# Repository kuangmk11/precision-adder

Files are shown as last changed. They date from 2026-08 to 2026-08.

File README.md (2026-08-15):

# Precision Adder v2.2
This is a precision CV source and adder. It has four stages, each with an input, an output and a passthru. Each stage's **output** normals down to the next stage's input, so with a single cable into `IN1` the stages cascade and their offsets sum; patching into any `IN` breaks the normal above it. The passthru is a buffered copy of that stage's input, so with nothing patched `PT2` = `OUT1`, `PT3` = `OUT2`, and so on.

Each section provides a different voltage to be added to the input: +/- 2v, +/- 1v, +/- .5833333v (a fifth), +/- .4166666v (a fourth)

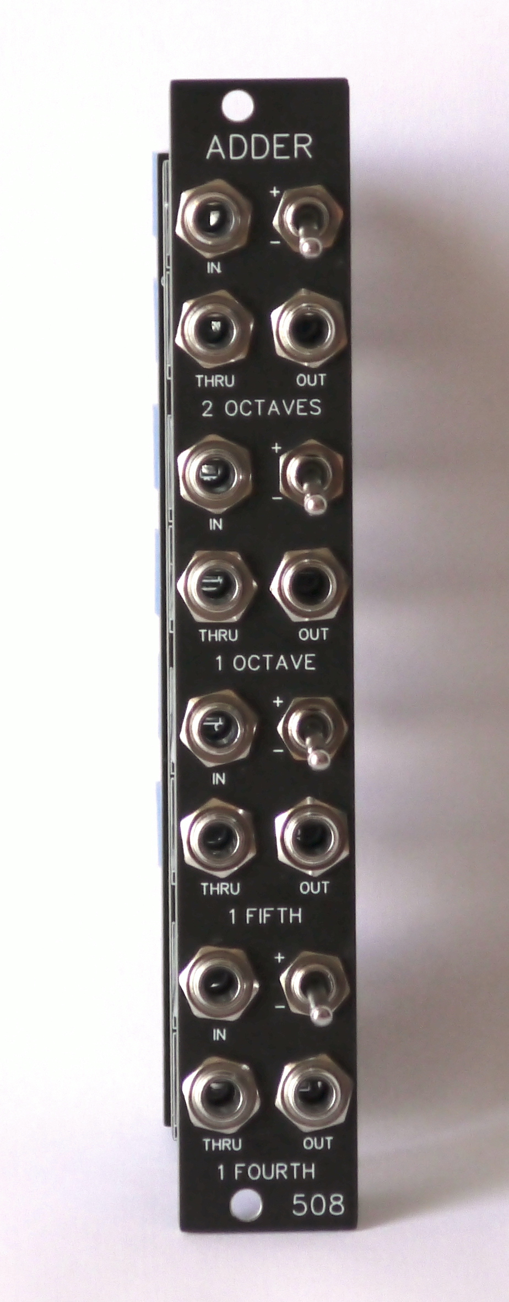
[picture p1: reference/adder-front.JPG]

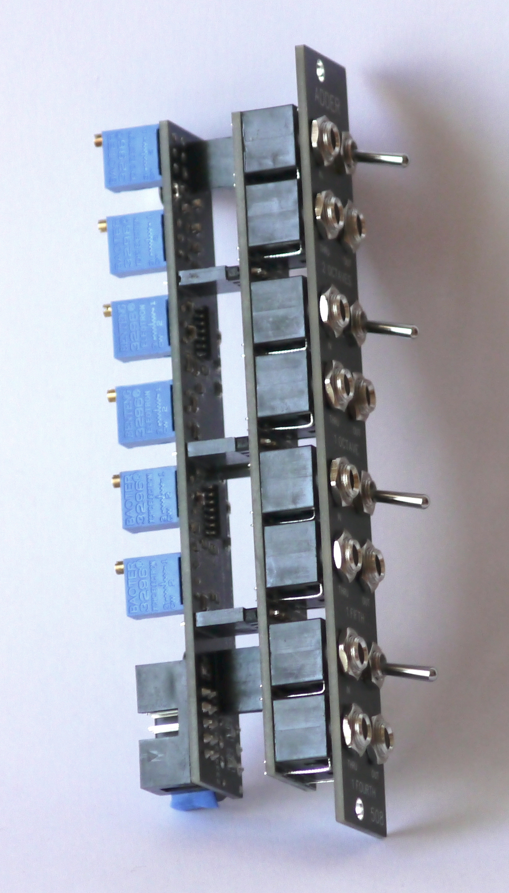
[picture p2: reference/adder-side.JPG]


## The v2.2 reference build

Everything shipped for the built v2.2 board now lives in [`reference/`](reference/): its
schematic PDF, the three gerber archives, the EasyEDA bill of materials and the photos
above. That revision is finished and is not being changed — the directory is there so the
built design stays available for anyone assembling a v2.2, and as the thing v3 is measured
against.

Two v2.2 documents deliberately stay outside it. [`docs/v2.2-topology.md`](docs/v2.2-topology.md)
is the ladder maths read off the v2.2 schematic, and it is a live input to v3 rather than an
artifact of the old build — `tools/gen_schematic.py` works from it, and `docs/v3-BOM.md`
verifies against it. [`docs/DESIGN-LOG.md`](docs/DESIGN-LOG.md) spans both revisions.

## Available intervals

The switches are SPDT ON-ON, so a stage in the chain always contributes either its positive or its negative offset — there's no center-off. Using the switches alone gives 4 stages x 2 states = **16 combinations** and 13 distinct voltages.

A stage can also be bypassed by patching its `PT` (passthru) into the `IN` of the next stage, feeding that stage's input forward instead of its output. That makes each stage a 3-state element (**+**, **-**, or **bypassed**), for **81 configurations** and **39 distinct voltages**.

The full set is symmetric, so the table below lists magnitudes only — for the negative of any row, flip every `+`/`-` (bypasses stay bypassed). `o` = stage bypassed.

| Semitones | Volts | Interval | Settings (2oct · 1oct · 5th · 4th) |
|---:|---:|---|---|
| 48 | 4.0000 | 4 oct | `+ + + +` |
| 43 | 3.5833 | 3 oct + 5th | `+ + + o` |
| 41 | 3.4167 | 3 oct + 4th | `+ + o +` |
| 38 | 3.1667 | 3 oct + M2 | `+ + + -` |
| 36 | 3.0000 | 3 oct | `+ + o o` · `+ o + +` |
| 34 | 2.8333 | 2 oct + m7 | `+ + - +` |
| 31 | 2.5833 | 2 oct + 5th | `+ + o -` · `+ o + o` |
| 29 | 2.4167 | 2 oct + 4th | `+ + - o` · `+ o o +` |
| 26 | 2.1667 | 2 oct + M2 | `+ o + -` |
| 24 | 2.0000 | 2 oct | `+ + - -` · `+ o o o` · `+ - + +` · `o + + +` |
| 22 | 1.8333 | 1 oct + m7 | `+ o - +` |
| 19 | 1.5833 | 1 oct + 5th | `+ o o -` · `+ - + o` · `o + + o` |
| 17 | 1.4167 | 1 oct + 4th | `+ o - o` · `+ - o +` · `o + o +` |
| 14 | 1.1667 | 1 oct + M2 | `+ - + -` · `o + + -` |
| 12 | 1.0000 | 1 oct | `+ o - -` · `+ - o o` · `o + o o` · `o o + +` |
| 10 | 0.8333 | m7 | `+ - - +` · `o + - +` |
| 7 | 0.5833 | 5th | `+ - o -` · `o + o -` · `o o + o` |
| 5 | 0.4167 | 4th | `+ - - o` · `o + - o` · `o o o +` |
| 2 | 0.1667 | M2 | `o o + -` |
| 0 | 0.0000 | unison | `o o o o` · `+ - - -` · `o + - -` · `o - + +` · `- + + +` |

### The pattern

Every reachable offset is **0, ±2, or ±5 semitones (mod 12)** — unison, M2, 4th, 5th, m7, and their octaves. Within ±48 semitones every such value is reachable *except* ±46. Thirds, tritones, sixths, and single semitones are not available, because a fifth and a fourth can only ever combine to an octave (7+5) or a whole step (7-5).

The usable pitch-class set is therefore the suspended pentatonic `{0, 2, 5, 7, 10}`, spread across a full ±4 octaves in 1/12 V steps.

### Patching notes

- **Leading bypasses are free** — plug your CV into `IN2` / `IN3` / `IN4` instead of `IN1`.
- **Trailing bypasses are free** — take your output from the last active stage's `OUT` instead of `OUT4`.
- **Only interior bypasses cost a cable**: one patch, `PTn` -> `IN(n+1)`, per skipped stage.
- Where a row lists multiple settings, prefer the one with bypasses at the edges — same voltage, fewer cables. For example 2 oct + 4th is `+ + - o` with no cables, versus `+ o o +` with two.

## v3 proposal (unbuilt)

v2.2 is a serial interval adder with a redundant interval set. v3 keeps the cascade, fixes the set, and reorganises the panel around what the cascade is actually good at — stacking intervals into chords.

The interval problem first: because a fifth plus a fourth is exactly an octave (7 + 5 = 12), two of v2.2's four stages collapse into a redundant third. 81 configurations produce only 39 distinct voltages, and the output can never leave the pitch classes `{0, 2, 5, 7, 10}` — no thirds, no sixths, no tritone, no single semitones.

### Four changes

**1. ON-OFF-ON switches.** v2.2 uses SPDT ON-ON, which is why bypassing a stage costs a patch cable. A subminiature ON-OFF-ON is the same footprint at essentially the same price, and the center detent gives each stage a native off position. Every configuration becomes reachable from the front panel with no patching. (Doepfer's A-185-2 has always done it this way — see the comparison below.)

**2. Drop `IN2`-`IN4` and `PT2`-`PT4`.** Outputs normal down to the next input, so with nothing patched `PT2` = `OUT1`, `PT3` = `OUT2`, `PT4` = `OUT3`. Those passthrus are duplicates of the output above them. The extra inputs existed to break the cascade, which the center-off switch now does better. Six jacks were doing the work of two.

**3. Sum three inputs at the front.** `IN1` + `IN2` + `IN3` at unity gain feed the head of the cascade. This is the multi-source summing the module is named for — keyboard plus sequencer plus offset — and it is what the freed panel space buys. `PT` becomes the buffered *sum* of the inputs: an untransposed root that stays put while the cascade transposes everything above it.

**4. Collapse the two octave stages into one, and make stages 2-4 thirds.** Stage 1 becomes a 5-state octave control (±1, ±2, off) from two toggles, freeing a stage. Stages 2 and 3 get a three-position quality switch selecting **4th / maj 3rd / min 3rd**, and stage 4 selects **5th / maj 3rd / min 3rd** — because stacked thirds are how chords are built, and the fifth on the last stage keeps the module's most-used interval one flip away.

### Panel

| | v2.2 | v3 |
|---|---:|---:|
| Jacks | 12 | 8 — `IN1` `IN2` `IN3` `PT` `OUT1`-`OUT4` |
| Switches | 4 | 8 — 2 per stage |
| **Positions** | **16** | **16** |

Same density as the board already built. No rotary, no new mechanical problem.



**This is a new panel, not v2.2's reused.** Earlier v3 drafts kept every v2.2 hole
position and only reassigned diameters, which forced the four outputs into two shared
rows. Grouping each stage instead — its two switches and its own output, boxed together —
needs six evenly spaced rows below the inputs, so the positions are refitted. The v3 main
board is new anyway.

Panel and drawing are generated by [`tools/gen_panel.py`](tools/gen_panel.py) from one
layout table, so they cannot disagree:

```sh
python3 tools/gen_panel.py            # writes the .kicad_pcb and the .svg, with a clearance report
python3 tools/gen_panel.py --table    # the hole schedule below
```

- [`docs/v3-panel.kicad_pcb`](docs/v3-panel.kicad_pcb) — board outline, holes and mounting
  slots on `Edge.Cuts`, silkscreen on `F.SilkS`. Holes are `Edge.Cuts` circles, so the fab
  routes rather than drills them; swap to NPTH pads if your fab prefers.
- [`docs/v3-panel.svg`](docs/v3-panel.svg) — the same geometry at 1:1 (1 unit = 1 mm,
  20 × 128.5 mm), for printing and review. The grey rings are hardware footprints — 8 mm
  Thonkiconn nut, 7.5 mm toggle nut — shown for clearance checking, not artwork, and not
  in the KiCad output.

Conventions — lettering, marks, label placement, mounting — are in
[`PANEL_STYLE_v1.02.md`](PANEL_STYLE_v1.02.md).

#### How it reads

Four jacks at the top: three summed inputs and `SUM`, the buffered sum that `PT` becomes.
`SUM` is an output, so it carries the ring — the panel's only closed circle, which is what
lets direction read at a glance. The ring has to clear the 8 mm nut to be visible at all,
and a 20 mm panel carrying two 8 mm nuts has 4 mm of slack in total, so at r 4.4 it ends up
0.28 mm from the cut on the outboard side. Still on the board, but well inside the 0.6 mm
edge margin, and a fab may trim the outer edge of it. Taken deliberately: a broken ring
reads worse than a clipped one. Below them, **four boxed groups, one per stage — polarity
switch, selector switch, that stage's output.** Each stage now owns its output, which the
old shared-row layout could not manage.

**Arrows trace the cascade** across the top pair, down into the bottom-left group, and
across the bottom pair — the order the stages actually sum in. The middle leg cannot be a
straight diagonal: about 4 mm of clear band between the box rows against a 10.8 mm column
pitch would need a 15° line, and the house routing is 0°, 90° and 45° only. So it drops,
takes a 45° knee, runs the band and turns down into the group it feeds. Where an arrow
crosses a box outline the outline is broken, the same way a group name breaks it.

`OUT1`–`OUT4` do not repeat the ring. Each already sits inside a named box that says which
stage it belongs to, and the style guide's rule against a second closed circle is what
keeps `SUM`'s ring meaningful. If you would rather every output ring, it is one line in the
generator.

Within a group: `+` above the polarity toggle, `−` below it, and **`0` beside its centre
detent**. The selector's two throws are labelled above and below it the same way.

That `0` matters more than it looks. A selector displays a value at all times, so without
it the panel reads as though a stage adds its interval even when the stage is switched off
— and the polarity toggle's centre, not the selector's, is what turns a stage off. One rule
covers both toggles now: **a three-position toggle's centre value is marked in the strip
between its nut and the box edge.** `OCT`'s magnitude switch is two-position and has no
centre, so it carries no such mark.

It is also why a plain fifth is one flip. At rest every polarity toggle is centred and the
module passes through untouched, whatever the selectors show; move stage 4's polarity to
`+` and its selector is already sitting on the `5`.

**The selector's centre detent carries the stage's odd interval** — the 4th on the two
`3RD` stages, the 5th on `5TH` — and the two throws are the two thirds, `MAJ` and `MIN`.
That is partly ergonomic, since the thirds are the pair you reach for when building a
chord, and partly forced: the centre mark is the only one with nowhere to go but the
1.2 mm strip between the toggle nut and the box, where a single character fits and two do
not. It is set at 1.0 mm, below the house 1.6 mm minimum, and is the one deliberate
exception on the panel.

#### Hole schedule

Origin top-left, millimetres, Y down — the drawing's own frame, not the old gerbers'.

| Y (mm) | X (mm) | Ø | What |
|---:|---:|---:|---|
| 16.60 | 4.80 | 6.0 | IN1 |
| 16.60 | 15.20 | 6.0 | IN2 |
| 28.60 | 4.80 | 6.0 | IN3 |
| 28.60 | 15.20 | 6.0 | SUM (output, ringed) |
| 44.80 | 4.80 | 5.0 | OCT polarity  +/o/− |
| 44.80 | 15.20 | 5.0 | 3RD polarity  +/o/− |
| 57.80 | 4.80 | 5.0 | OCT select  1/2 |
| 57.80 | 15.20 | 5.0 | 3RD select  MAJ/MIN (detent 4) |
| 68.80 | 4.80 | 6.0 | OUT1 |
| 68.80 | 15.20 | 6.0 | OUT2 |
| 88.00 | 4.80 | 5.0 | 3RD polarity  +/o/− |
| 88.00 | 15.20 | 5.0 | 5TH polarity  +/o/− |
| 101.00 | 4.80 | 5.0 | 3RD select  MAJ/MIN (detent 4) |
| 101.00 | 15.20 | 5.0 | 5TH select  MAJ/MIN (detent 5) |
| 112.00 | 4.80 | 6.0 | OUT3 |
| 112.00 | 15.20 | 6.0 | OUT4 |
| 3.00 | 12.50 | 6.4×3.2 | mounting slot, obround |
| 125.50 | 7.50 | 6.4×3.2 | mounting slot, obround |

Mounting follows the style guide's ≤ 6 HP rule: one 6.4 × 3.2 mm horizontal slot top-right
and one bottom-left, so the module can slide ±1.6 mm to meet its neighbours and cannot
pivot on a single screw per rail. v2.2's round Ø3.2 holes do not carry over.

#### What the generator checks, and what it cannot

`gen_panel.py` refuses to write if anything overlaps, and reports the tightest clearance in
each category. Currently: **0.15 mm** text-to-nut, **0.64 mm** text-to-text, **0.15 mm**
text-to-silk, **0.42 mm** text-to-ring, **0.60 mm** silk-to-edge, **1.40 mm** of material
at the worst hole, and **2.40 mm** between the closest two nuts. `SUM`'s ring is exempted
from the edge margin and reported separately, so the exception stays visible instead of
being absorbed into a looser rule.

Those come from a stroke-glyph model that assumes ink fills 0.62 em of each character
cell — conservative for the KiCad stroke font, but still a model. **KiCad's own DRC passes
with 0 violations and 0 unconnected items** (`tools/kicad-check.sh`), and the board plots
correctly from KiCad, mounting slots and all.

The two toggles in a group are 13.0 mm apart, leaving 5.5 mm between their nuts — up from
4.9 mm in the row-based draft, but still unproven on this hardware, since v2.2 stacks no
toggles at all. Print the SVG at 100%, check it measures 20 × 128.5 mm, and try the pairs
with real fingers.

### Schematic

[`docs/v3-adder.kicad_sch`](docs/v3-adder.kicad_sch), generated by
[`tools/gen_schematic.py`](tools/gen_schematic.py) from a netlist table:

```sh
python3 tools/gen_schematic.py             # writes the .kicad_sch, with a design report
python3 tools/gen_schematic.py --bom       # bill of materials
python3 tools/gen_schematic.py --netlist   # every net and what is on it
```

**It is a scaffold, not a finished drawing.** Connectivity is complete and correct;
placement is a plain grid, and every connection is made with a net label on a short pin stub
rather than by routing wires. That is deliberate — label-based connectivity cannot be got
subtly wrong the way routed wires can, and rearranging symbols in KiCad afterwards breaks
nothing. Expect to spend time on layout, not on wiring.

Topology follows [`docs/v2.2-topology.md`](docs/v2.2-topology.md). The reference block, the
power block and the summing topology are v2.2's, unchanged. 102 parts, 72 nets, 12 op-amp
channels across three OPA4196 — 11 used, one spare tied off as a follower.

**Only the lower ladder segments need to be precise.** A tap's voltage is set by the ratio
of the segments below it to the whole chain, and the trimmer sits in series at the top, so
the top segment's absolute value is absorbed by trimming — which is why the BOM shows
5.5k, 24.5k and 22.5k and why that does not matter. Use the nearest E96 part and let the
trimmer take up the difference. What does matter is the ratio between the small segments
(1k, 3k, 12k), and that is where hand-matched parts earn their keep.

Alongside the schematic the generator writes `adder.kicad_sym`, `v3-adder.kicad_pro` and a
`sym-lib-table`, so the project opens with its symbol library resolved rather than warning
once per symbol.

**KiCad's own ERC passes with 0 errors.** Run it yourself:

```sh
KICAD_CLI="/path/to/kicad-cli" tools/kicad-check.sh    # ERC, DRC and plots into .kicadcheck/
```

The 23 remaining ERC warnings are all `footprint_link_issues` on the custom parts — jacks,
toggles, trimmers, ferrites, the Eurorack header. Those footprints are yours to supply, and
a name that does not resolve is a more honest placeholder than a wrong one that does. Stock
KiCad footprints are used everywhere they exist, so the passives, op-amps, regulators and
diodes resolve on any install.

### Bill of materials

[`docs/v3-BOM.md`](docs/v3-BOM.md) is the parts list, with the tolerance reasoning for every
line. [`docs/BOM_v3_DigiKey.csv`](docs/BOM_v3_DigiKey.csv) alongside it is an upload-ready
DigiKey list covering 93 of the parts; its sourcing notes are the last section of `v3-BOM.md`.

Three things are worth knowing before ordering. The **E24 values this design depends on are
stocked in 0.1 %** — Panasonic's ERA-8 series has both the 3.00k and the 12.0k, so choosing E24
over E96 for the exact 3:1 ratio costs nothing in availability. The **ON-ON-ON DPDT has no
DigiKey equivalent** in this form factor and must come from a synth DIY shop, along with the
jacks and the axial ferrites. And **C9/C10 need a decision**: the MnO2 tantalum that satisfies
the ESR requirement is a surface-mount part, which does not fit the through-hole footprint the
BOM currently specifies for them.

#### Switches

Taiway series 200 subminiature throughout — `T1` actuator, `B1` bushing, `M2` PC thru-hole,
`Q` silver, `E` epoxy:

| Function | Part | Used for |
|---|---|---|
| SPDT ON-OFF-ON | `200-MSP3-T1B1M2QE` | polarity, ×4 |
| SPDT ON-ON | `200-MSP1-T1B1M2QE` | `OCT` magnitude, ×1 |
| DPDT ON-ON-ON | `200-MDP6-T1B1M2QE` | quality selectors, ×3 |

The `B1` bushing is **10-48 UNS, Ø4.80** and Taiway's recommended panel hole is **Ø4.95** —
the panel's Ø5.0 is right. There is also an optional 4.55 mm flat in the hole for
anti-rotation, which the panel does not cut, so the switches are held by nut torque alone.

**A DPDT ON-ON-ON is a 1-of-3 selector only if you cascade its poles.** Pins 1‑2‑3 are pole
A with 2 common, 4‑5‑6 are pole B with 5 common. Pole A's common is the output; one of its
throws is a tap outright, the other feeds pole B's common, and pole B picks between the
remaining two. Tying the commons together instead would short two ladder taps in every
position.

`MDP-6`'s contact sequence, from Taiway:

| Position | Contacts |
|---|---|
| 1 | `2-3, 5-6` |
| 2 (centre) | `2-3, 5-4` |
| 3 | `2-1, 5-4` |

`ONONON_VARIANT = 1` in `tools/gen_schematic.py` encodes exactly this. `check_selector()`
walks each selector through all three positions from that table and asserts the output
reaches the intended tap and **exactly one** tap — the property that makes the cascade
trustworthy, since getting it wrong shorts two points of a resistor ladder rather than
failing loudly. Setting the variant to 2 makes it fail at the centre detent, as it should.

PC-mount terminals are on a **5.08 × 2.54 mm** grid, six pins, numbered 6‑5‑4 down one
column and 3‑2‑1 down the other.

**Orientation does not matter.** The body is symmetric, so fitting it 180° round swaps
diagonally opposite pads (6↔1, 5↔2, 4↔3) *and* reverses the lever — and those two cancel
exactly. Read against the board's own pad numbers from lever-up to lever-down, the sequence
is unchanged. The pin numbers on a reversed part are wrong; its behaviour is not.
`check_rotation_symmetry()` asserts this against the contact table, so it stays true if the
table is ever edited.

The generator additionally checks, before writing: every `lib_id` resolves as a full
`library:name` string and every instantiated unit has a matching body; every pin coordinate
read back out of the written file lands on a wire endpoint, so the label stubs really do
attach; no pin is unconnected; no net has fewer than two connections; no reference is used
twice and no pin appears on two nets; and every ladder tap computes to its interval voltage
exactly with the trimmer centred.

### Stages

Read the selector column as **up / _centre detent_ / down**, which is how the panel is
marked: the two throws are the thirds, the detent is the stage's odd interval.

| Stage | Panel group | Control | Selects — up / _detent_ / down | Values | Volts |
|---|---|---|---|---|---|
| 1 | `OCT` | on-off-on + `1/2` on-on | 1 oct / — / 2 oct | ±12, ±24 st | 1.000000 / 2.000000 |
| 2 | `3RD` | on-off-on + quality on-on-on | M3 / _4th_ / m3 | ±4, ±5, ±3 st | 0.333333 / 0.416667 / 0.250000 |
| 3 | `3RD` | on-off-on + quality on-on-on | M3 / _4th_ / m3 | ±4, ±5, ±3 st | 0.333333 / 0.416667 / 0.250000 |
| 4 | `5TH` | on-off-on + quality on-on-on | M3 / _**5th**_ / m3 | ±4, ±7, ±3 st | 0.333333 / 0.583333 / 0.250000 |

The values are unchanged from earlier drafts — only which throw carries which. Stage 1's
magnitude switch is a two-position ON-ON, so it has no detent.

Stage 4 takes a **5th** where stages 2 and 3 take a 4th. That buys back the one-switch fifth — the module's most-used interval — and on the chord side it turns stage 4 into an extension selector, since stages 2 and 3 have already built the triad by the time the signal reaches it.

**1715 configurations, 83 distinct voltages, fully chromatic across ±41 semitones (±3.42 octaves), all 12 pitch classes.**

### Chords

The cascade means each output is a running sum, so `OUT1`-`OUT4` are stacked intervals, with `PT` available as an untransposed root beneath them. **Stages 2 and 3 set the triad; stage 4 sets the extension.**

| Triad (st2 + st3) | st4 = m3 | st4 = M3 | st4 = 5th |
|---|---|---|---|
| M3 + m3 — **major** | dominant 7th | major 7th | add9 |
| m3 + M3 — **minor** | minor 7th | minor-major 7th | minor add9 |
| m3 + m3 — **diminished** | diminished 7th | half-diminished | dim add b9 |
| M3 + M3 — **augmented** | augmented maj7 | augmented (8ve) | augmented #9 |

Twelve voicings from three switches, and the triad is already correct on `OUT1`-`OUT3` before stage 4 is touched. The 4th position on stages 2 and 3 adds sus and quartal voicings on top of that.

The `OCT` stage transposes the whole chord while `PT` holds the original root — so a pedal tone stays put underneath a transposed voicing.

This is what the old `{octave, 5th, 4th, maj 3rd}` set could not do: fifths and fourths do not stack into chords.

### Transposition chart

Taking `OUT4` as a single transposed voice. `o` = switch centered. Within any octave the settings are identical, so the `OCT` stage handles everything above; negative intervals are the mirror image.

| Semitones | Volts | Interval | OCT | st2 | st3 | st4 | Flips |
|---:|---:|---|:---:|:---:|:---:|:---:|---:|
| 0 | 0.0000 | unison | `o` | `o` | `o` | `o` | 0 |
| 1 | 0.0833 | min 2nd | `o` | `o` | `+4th` | `-M3` | 2 |
| 2 | 0.1667 | maj 2nd | `o` | `o` | `+4th` | `-m3` | 2 |
| 3 | 0.2500 | min 3rd | `o` | `o` | `o` | `+m3` | 1 |
| 4 | 0.3333 | maj 3rd | `o` | `o` | `o` | `+M3` | 1 |
| 5 | 0.4167 | 4th | `o` | `o` | `+4th` | `o` | 1 |
| 6 | 0.5000 | tritone | `o` | `o` | `+m3` | `+m3` | 2 |
| 7 | 0.5833 | 5th | `o` | `o` | `o` | `+5th` | **1** |
| 8 | 0.6667 | min 6th | `o` | `o` | `+4th` | `+m3` | 2 |
| 9 | 0.7500 | maj 6th | `o` | `o` | `+4th` | `+M3` | 2 |
| 10 | 0.8333 | min 7th | `o` | `o` | `+m3` | `+5th` | 2 |
| 11 | 0.9167 | maj 7th | `o` | `o` | `+M3` | `+5th` | 2 |
| 12 | 1.0000 | octave | `+1` | `o` | `o` | `o` | 1 |

Every interval up to the octave is one or two switch positions, and the octave, 4th, 5th, maj 3rd and min 3rd are all single flips. The remaining rows read as stacks — a tritone is two minor thirds, a major 7th is a major third over a fifth.

### Build notes

- **BOM:** 4x `SUBMINI_SPDT ON-OFF-ON` (polarity, one per stage), 3x `ON-ON-ON` DPDT (quality, stages 2-4), 1x `ON-ON` (octave magnitude). 8 jacks instead of 12.
- Resistor values needed: 1.000000 and 2.000000 V (already on the v2.2 board), 0.583333 V (the existing 5th) and 0.416667 V (the existing 4th), plus 0.333333 V and 0.250000 V (new). Every v2.2 divider is reused; only the two third values are added.
- The three input summing resistors must be matched — this is where the "precision" in the name is spent. Doepfer specs 0.1% on the A-185-2 for the same reason.
- **Headroom:** three summed inputs plus up to ±3.25 octaves of offset can rail a ±12 V supply. Worth checking the worst case for the intended sources rather than assuming.
- No normalling on `IN2`/`IN3` — an unpatched input should contribute 0 V, not a fixed offset. (Doepfer normals its inputs to +1 V so they double as octave switches; here the octave stage already does that job.)
- All inputs stay at unity gain. An attenuator on one input would be useful for modulation depth, but it compromises the precision identity — that is the A-185-2's tradeoff, not this one's.

## Comparison: Doepfer A-185-2

The obvious commercial reference point, and the source of the ON-OFF-ON idea. (The A-185-2V is the Vintage Edition — beige panel, functionally identical.)

The A-185-2 is a **summer first and an offset generator second**. It has four CV inputs — one with a log attenuator, three without — each with a three-position add/off/subtract switch, and every input normalled to +1 V. Its intended job is combining keyboard + sequencer 1 + sequencer 2; the offset capability falls out of the normalling. Unpatched, you get three switches at ±1 octave plus the attenuated channel as a continuous 0...±1 V fine tune. Total range ±4 V, the same as v2.2, but the switched part is only `{0, ±12, ±24, ±36}` semitones — 7 distinct values out of 27 combinations, since all three sections are the same 1 V.

| | A-185-2 | v2.2 | v3 |
|---|---|---|---|
| Width | 6 HP | — | — |
| Summing inputs | 4 (1 attenuated) | 1 (+3 cascade breaks) | 3 |
| Interval stages | 4 | 4 | 4 |
| Switch type | ON-OFF-ON | ON-ON | ON-OFF-ON + ON-ON-ON |
| Bypass a stage | center detent | patch `PT`->`IN` | center detent |
| Offset values | 1 V x3 (octaves only) | 2, 1, 0.5833, 0.4167 V | 1/2 oct; 4th/M3/m3 x2; 5th/M3/m3 |
| Switched distinct values | 7 | 39 | 83 |
| Non-octave intervals | knob only, not exact | exact 4th/5th | exact 3rd/4th/5th |
| Fully chromatic | via knob, unrepeatable | no (5/12 pitch classes) | yes, ±41 st |
| Chord voices | 1 | 4 (cumulative) | 4 + root, 12 voicings |
| Inverting output | yes | no | no |
| Input attenuator | yes (log) | no | no |
| Outputs | 3x sum + 1x inverted | per-stage taps | per-stage taps + `PT` |
| A-100 bus CV | yes (JP5) | no | no |
| Accuracy | 0.1% matched | — | — |

**What the Doepfer cannot do:** produce an exact fifth. Its only non-octave path is a log potentiometer — you can get close by ear, but not to 0.583333 V repeatably, and not back to it after moving the knob. That gap is the reason this module exists.

**What this module cannot do:** invert or attenuate its input, or reach the A-100 bus. The ± switches negate each stage's own contribution, not the incoming CV; the A-185-2's inverting output negates the entire sum. That is a real feature absent here and not fakeable with the current topology.

They are complementary rather than competing — the Doepfer is the better general-purpose summer, this is the better interval and chord source. v3 narrows the gap on summing by taking three inputs at the front. The one thing worth taking wholesale is the switch: center-off is a BOM choice, not a design constraint, and v2.2 pays a patch cable per bypass for want of it.

Sources: [A-185-2 specification](https://doepfer.de/a185_2.htm), [Doepfer product page](https://www2.doepfer.eu/en/item/a185-2).

## Appendix: interval set study

Where the v3 numbers come from. All of it is reproducible with [`interval-study.py`](interval-study.py) (no dependencies, `python3 interval-study.py`).

### Method

Each stage contributes `+v`, `-v`, or `0`, so N stages give 3^N configurations. On v2.2 the zero state costs a patch cable (`PT` -> `IN` of the next stage) because the switches are ON-ON; on v3 it is the center detent of an ON-OFF-ON. The arithmetic is identical either way, so every chart below applies to both. Values are in semitones; 1 semitone = 1/12 V. Three metrics are reported:

- **distinct** — how many different output voltages the module can produce. Below the combination count means stages are redundant with each other.
- **chromatic ±N** — the widest symmetric range around 0 in which *every* semitone is reachable. This is the metric that matters; a set can have plenty of distinct values and still be useless for chromatic work.
- **pc** — how many of the 12 pitch classes are reachable at all.

Baseline for v2.2 `{24,12,7,5}`: **39 distinct / 81 combos, chromatic ±0, 5/12 pitch classes.**

### Chart 1 — one stage added to v2.2

| Added | Interval | Distinct | Chromatic | Pitch classes |
|---:|---|---:|---:|---:|
| +1 | min 2nd | 95 | ±44 | 12/12 |
| +2 | maj 2nd | 73 | ±0 | 9/12 |
| +3 | min 3rd | 89 | ±5 | 11/12 |
| **+4** | **maj 3rd** | **97** | **±45** | **12/12** |
| +5 | 4th | 57 | ±0 | 7/12 |
| +6 | tritone | 83 | ±2 | 10/12 |
| +7 | 5th | 57 | ±0 | 7/12 |
| +8 | min 6th | 99 | ±44 | 12/12 |
| +9 | maj 6th | 89 | ±5 | 11/12 |
| +10 | min 7th | 75 | ±0 | 9/12 |
| +11 | maj 7th | 99 | ±38 | 12/12 |
| +12 | octave | 49 | ±0 | 5/12 |

A major third is the best single addition — widest chromatic range, all 12 pitch classes, and musically it is what turns octave/fifth stacking into triads. Note the traps: the minor third and major sixth look appealing but top out at 11/12 pitch classes, and the one they cannot reach is the tritone. Adding another 4th, 5th, or octave is nearly worthless, because those are already in the span of the existing stages.

### Chart 2 — best 4-value sets, unconstrained (search 1..27)

| Set | Distinct | Chromatic |
|---|---:|---:|
| **(1, 3, 9, 27)** | **81/81** | **±40 (3.33 oct)** |
| (2, 3, 9, 27) | 81/81 | ±39 (3.25 oct) |
| (1, 3, 9, 26) | 79/81 | ±39 (3.25 oct) |
| (1, 3, 9, 25) | 77/81 | ±38 (3.17 oct) |
| (3, 4, 9, 27) | 81/81 | ±37 (3.08 oct) |
| (1, 6, 9, 27) | 81/81 | ±37 (3.08 oct) |
| (2, 3, 9, 25) | 77/81 | ±37 (3.08 oct) |
| (1, 3, 9, 24) | 75/81 | ±37 (3.08 oct) |

`{1, 3, 9, 27}` is balanced ternary — each stage 3x the one before, which is exactly the condition for no combination to duplicate another. 81 configurations produce 81 distinct voltages covering every semitone from -40 to +40, each by exactly one switch setting. No four values can beat this, because 81 states cannot cover more than 81 notes.

Voltages: 1 st = 1/12 = 0.083333 V, 3 st = 1/4 = 0.250000 V, 9 st = 3/4 = 0.750000 V, 27 st = 9/4 = 2.250000 V. Three of the four are exact quarter-volt multiples in a 1:3:9 ratio off a single reference, so it is also the cleanest of these to build.

**This is the theoretical maximum, and v3 does not use it.** No four values reach further or waste less. But the panel would be unplayable: 2 octaves is `27 - 3`, a fourth is `9 - 3 - 1`, and reading an interval off the switches means decoding balanced ternary. It is the right answer to "how many distinct voltages can four switches make" and the wrong answer to "what should the panel say." See Chart 8.

### Chart 3 — constrained: keep both octave stages (12 and 24)

| Set | Distinct | Chromatic |
|---|---:|---:|
| {24,12,9,11} | 63/81 | ±4 |
| {24,12,3,11} | 63/81 | ±4 |
| {24,12,1,9} | 63/81 | ±4 |
| {24,12,1,3} | 63/81 | ±4 |
| {24,12,9,10} | 63/81 | ±3 |

This is the case against keeping the v2.2 layout. Spending two of four stages on octaves leaves only two to fill twelve semitones, and nothing does better than ±4. The octave stages are the problem, not the fifth and fourth.

### Chart 4 — constrained: keep one octave stage (12)

| Set | Distinct | Chromatic |
|---|---:|---:|
| {12,1,9,27} | 81/81 | ±31 |
| {12,2,9,27} | 81/81 | ±30 |
| {12,4,11,25} | 79/81 | ±30 |
| {12,4,13,23} | 77/81 | ±29 |

Keeping one labeled octave switch is affordable — still 81/81 distinct, at a cost of about 20% of the chromatic range versus pure ternary.

### Chart 5 — collapsed octave stage, best 3-value fill

With stage 1 collapsed to a 5-state element (±big, ±small, bypassed), three stages remain free. 135 configurations.

| Magnitude switch | Fill | Distinct | Chromatic |
|---|---|---:|---:|
| 1V/2V | (4, 9, 19) | 93 | ±40 (3.33 oct) |
| 1V/2V | (1, 9, 15) | 87 | ±40 (3.33 oct) |
| 1V/2V | (2, 9, 15) | 87 | ±39 (3.25 oct) |
| **1V/3V** | **(1, 3, 9)** | **99** | **±49 (4.08 oct)** |
| 1V/3V | (2, 3, 9) | 99 | ±48 (4.00 oct) |
| 1V/3V | (1, 3, 8) | 97 | ±48 (4.00 oct) |

### Chart 6 — four stages added to v2.2 (8 total, 6561 combos)

| Added | Distinct | Chromatic |
|---|---:|---:|
| (8, 9, 11, 12) | 167 | ±81 (6.75 oct) |
| (8, 10, 11, 12) | 167 | ±79 (6.58 oct) |
| (8, 9, 10, 11) | 163 | ±79 (6.58 oct) |
| (4, 10, 11, 12) | 163 | ±78 (6.50 oct) |

Included for completeness — an expander rather than a revision. Note the diminishing returns: 6561 configurations yield only 167 distinct voltages. That is not mainly redundancy, it is arithmetic — output range is bounded by the *sum* of the stage values (here 88 semitones, so 177 integers maximum), which grows linearly while configurations grow as 3^N. Small values like these are close to saturating what is available. Beyond about four well-chosen stages, extra stages buy range, not resolution.

### Chart 7 — summary

| Design | Distinct | Combos | Chromatic | Pitch classes |
|---|---:|---:|---:|---:|
| v2.2 {24,12,7,5} | 39 | 81 | ±0 | 5/12 |
| ternary {1,3,9,27} | 81 | 81 | ±40 (3.33 oct) | 12/12 |
| collapsed 1V/2V + {1,3,9} | 75 | 135 | ±37 (3.08 oct) | 12/12 |
| collapsed 1V/2V + {4,9,19} | 93 | 135 | ±40 (3.33 oct) | 12/12 |
| collapsed 1V/3V + {1,3,9} | 99 | 135 | ±49 (4.08 oct) | 12/12 |
| collapsed 1V/2V + {4,2,1} | 63 | 135 | ±31 (2.58 oct) | 12/12 |
| collapsed 1V/2V + {7,5,4} | 73 | 135 | ±33 (2.75 oct) | 12/12 |
| **oct + {5,4,3},{5,4,3},{7,4,3}** (v3) | **83** | **1715** | **±41 (3.42 oct)** | **12/12** |

### Chart 8 — usability

Range is not the only axis, and on its own it picks the wrong design. Two ergonomic measures:

- **max fill** — the largest number you ever have to reach on the non-octave stages. At or below 12 you never count past an octave in your head.
- **flips** — switches moved from all-off to reach an interval. With ON-OFF-ON switches this is literal; on v2.2 hardware some of these "flips" are patch cables instead, which is a further argument for the center-off variant.

| Design | Chromatic | Max fill | Intervals reachable | Avg flips | Mental model |
|---|---:|---:|---:|---:|---|
| v2.2 {24,12,7,5} | ±0 | 48 | 5/12 | 1.60 | interval names |
| ternary {1,3,9,27} | ±40 | 40 | 12/12 | 2.00 | balanced ternary |
| collapsed 1V/3V + {1,3,9} | ±49 | 13 | 12/12 | 1.83 | balanced ternary |
| collapsed 1V/2V + {4,2,1} | ±31 | 7 | 12/12 | 1.83 | binary 0-7 |
| **collapsed 1V/2V + {7,5,4}** | **±33** | **16** | **12/12** | **1.83** | **interval names** |

Cost per interval, cheapest setting:

| Interval | v2.2 | 1V/2V + {7,5,4} | 1V/2V + {4,2,1} | 1V/3V + {1,3,9} |
|---|---|---|---|---|
| min 2nd | — | 2 | 1 | 1 |
| maj 3rd | — | **1** | 1 | 2 |
| 4th | 1 | **1** | 2 | 3 |
| tritone | — | 3 | 2 | 2 |
| 5th | 1 | **1** | 3 | 3 |
| maj 6th | — | 2 | 3 | 1 |
| octave | 1 | **1** | 1 | 1 |
| oct + 5th | 2 | **2** | 3 | 4 |
| 2 octaves | 1 | **1** | 1 | 3 |

All three complete designs average 1.83 flips, so the average is not the deciding number — the *distribution* is. `{7,5,4}` spends its one-flip settings on the octave, fifth, fourth, and major third; the ternary set spends them on the minor 2nd, minor 3rd, and major 6th. The binary fill `{4,2,1}` is the honest middle (plain addition to 7, labelable as M3 / tone / semitone) but makes the fifth a three-flip operation to buy chromatic coverage that `{7,5,4}` already provides.

Note that `{7,5,4}` has the worst "max fill" of these at 16, because the tritone and a few neighbours are cheapest via a fifth plus a fourth plus a third. In practice this never bites: the fill settings repeat identically in every octave, so the settings repeat identically in every octave.

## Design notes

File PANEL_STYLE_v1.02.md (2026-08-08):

# Front panel style

**Version 1.02.**

House style for my module front panels — what marks go on them, what each one means, and
where it sits. It is a drawing spec, not a program: a panel is in the style if it satisfies
the rules below, whether it was generated or drawn by hand.

The look is borrowed from RYO's *Altered States* (`reference.jpg`) and is deliberately
PCB-native: single-weight plotter lettering, connections routed the way a trace is routed,
and dots where a silkscreen would have vias. Printed as white silkscreen on black
soldermask.

The rules were fitted to a set of eleven generated Kassutronics panels. That is where the
numbers come from, and why some are stated to the hundredth of a millimetre — they were
measured off production artwork, not chosen.

## Two ways to draw one

**Generated.** One `<stem>.layout.json` per panel says what its controls are and how they
relate; every mark comes from a single style library, so changing a number there changes
every panel at once.

```sh
tools/build_styled_panels.sh            # every finished layout
tools/build_styled_panels.sh Slope      # just the ones whose path matches
```

Outputs land beside each source as `<stem>.styled.{panel.json,kicad_pcb,svg}`, leaving the
PDF-derived conversions untouched.

**Drawn.** A hand-written SVG at 1:1, one user unit = 1 mm — `docs/v3-panel.svg` in this
repo is one. Nothing below needs a generator; the tokens are just numbers.

Where a rule is easier to state as tool behaviour ("the composer refuses to write if…"), it
is stated here as the rule being enforced. A generator should enforce it. A hand drawing has
to be checked.

## The one rule that is not negotiable

**Control hole positions are inherited, never computed.**

A panel serving a board that already exists — a port of someone else's module, or a revision
like this adder's v3 — takes its hole positions from that board and may not move them. A
panel whose holes move stops fitting its main board. v3 reassigns hole *diameters* between
6 mm jack and 5 mm toggle and keeps all sixteen positions from the built v2.2 panel.

On a genuinely new board the positions are fitted once, when the board is laid out, and are
inherited from then on.

Either way, **every hole is accounted for**, so a jack cannot silently vanish because a
layout forgot it.

Mounting holes are the exception: they meet the rails, not the module's own board, so they
are regenerated (below).

## Tokens

Every value is one number in one place. A generator holds them together; a hand drawing
copies them from here.

| | value | |
|---|---|---|
| `LINE_W` / `RULE_W` | 0.25 / 0.20 mm | wires, brackets, rings / centre divider |
| `LABEL_SIZE` / `PITCH_LABEL` | 2.0 / 2.2 mm | control labels |
| `SMALL_SIZE` / `PITCH_SMALL` | 1.6 / 1.7 mm | crowded rows, notes, bracket labels |
| `TITLE_SIZE` / `PITCH_TITLE` | 3.2 / 3.4 mm | module name |
| `LOGO_SIZE` / `PITCH_LOGO` | 1.3 / 1.45 mm | wordmark |
| `TRAVEL_DOT_D` / `TRAVEL_END_D` | 0.9 / 1.4 mm | knob travel marks |
| `DOT_D` | 0.6 mm | star-field, when used at all |
| `RING_GAP` | 1.2 mm | output ring stands off the hole edge |
| `EDGE_MARGIN` | 0.6 mm | no silkscreen closer than this to the cut |

**Tracking.** The reference's lettering is monospaced and widely tracked; stroke fonts
(Newstroke, and most plotter faces) are proportional, and KiCad has no letter-spacing
setting. So text is set **one character at a time** on a fixed pitch, each centred in its
own cell. Everything is uppercase.

## Marks and what they mean

**Knob travel — a dotted arc.** Eleven dots every 30°, at every position except +90°; the
gap at the bottom is where the label goes and the two dots either side of it, at +120° and
+60°, are the ends of travel and are drawn heavier. These positions are not invented: they
are measured off the starbursts on the ASR, both Attenumix panels and the Avalanche VCO,
which all draw the same 300° pot. The radius sits inside the band that artwork occupies —
3.75 to 8.06 mm on a 7.5 mm pot — so the marks stay visible with a knob fitted.

```
        ·  ·  ·               11 dots, r = hole_r + 3.45
      ·         ·
    ·     (O)     ·           hole
      ·         ·
     ●           ●            heavy: ends of travel, +120 / +60
          FOLD                the 30 deg gap at +90
```

- a **small** knob pulls the radius in for tightly spaced rows (Slope's Shape/Sustain sit on
  13.3 mm centres);
- a **big** knob draws **two** concentric rings, for an oversized main knob whose starburst
  runs out to 18.5 mm rather than 8.5 — the 3340 and KS-20 Frequency, the Ladder Filter, the
  Wavefolder's Fold;
- **bipolar** adds a heavier dot at 12 o'clock for the centre detent, and sets `-` / `+`
  outside the travel ends;
- **named ends** do the same with words, for the KS-20's `LP` / `HP` Mode.

**A ring means signal leaves here.** Every jack is an input or an output, and an output
draws the ring. Keeping it the only closed circle on a panel is what lets direction read at
a glance — which is also why nothing else may be a closed circle.

**A bracket groups one direction only.** It says *these belong together*, so enclosing an
input and an output in one misstates the signal flow. A bracket that mixes directions is an
error, not a judgement call. Labels sit in gaps in the bracket's own top edge. An output row
inside a bracket does not also get rings — the bracket already says it.

**An outline groups by function, not direction.** A plain rounded box at the lighter rule
weight, drawn round everything belonging to one section — the Quantizer's two channels, each
of which necessarily has both an input and an output, so the bracket's one-direction rule
does not apply. Where a bracket labels a row in its own top edge and must not mix
directions, an outline just says *this lot is one thing*.

**A span is one shared label** over a bar covering the controls it names, with a tick turning
down at each end — the 3340's two V/Oct inputs get one word, not the same word twice.

**A wire is a connection**, routed with one knee using only 0°, 90° and 45° segments,
stopping short of what it joins and breaking around any label it passes under. Routing does
**not** avoid obstacles: check that a wire does not cross a control, or drop it.

## Layout

**A name goes below the thing it names.** Every jack, every LED, every pot, every switch —
one rule, no exceptions, measured from whatever is drawn around the hole (a pot's travel
ring, an output's ring) and not from the hole itself. A panel where some names sit above
and some below makes the reader work out which each time.

**A mark that means a position goes where that position is.** Travel dots ring the pot,
`+` and `−` straddle a toggle, selector values stack beside the throws they select. These
are not names and the rule above does not apply to them — a `+` under a switch is wrong
however consistent it looks.

That leaves the case where a switch needs a name *and* position marks. The name takes the
baseline of the topmost position mark, off to one side of it. It must not sit directly
outboard of a `+` on the same baseline, or the two read as one word — `+OCTAVE`.

Three things adjust themselves and should not be fought:

- a row whose labels would collide, or would need shoving back inside the board, drops to the
  small size **as a whole row**;
- every label in a row is snapped to one baseline, so a ringed output does not sit 1.2 mm
  below its plain neighbours;
- the title shrinks to fit the clear span between the mounting slots.

When a row still needs help, in the order to reach for it: the small size, a larger label
gap, the label moved to a named direction, the label placed at an explicit `[x, y]`. An
explicit title height and size exist for panels where a control near the top leaves only
~2 mm of clear band.

## Mounting

Regenerated to one rule, as 6.4 × 3.2 mm obround slots milled on Edge.Cuts — horizontal, so
a module can slide ±1.6 mm to meet its neighbours.

| | |
|---|---|
| vertical | centre 3.0 mm from the top and bottom edges |
| horizontal | centre 7.5 mm in from the edge; the opposite column steps out by N × 5.08 mm |
| **> 6 HP** | both columns, 4 slots — 8 HP at 7.5 / 32.9, 10 HP at 7.5 / 43.06 |
| **≤ 6 HP** | one slot top and bottom on **opposite corners**, top right and bottom left. One screw per rail is enough at that width, and diagonal placement stops the module pivoting. |

The 7.5 mm inset is the datum and the grid steps out from it, so the far margin lands at
7.26–7.44 rather than exactly 7.5. That is the way round that matters: the grid is what the
rail is drilled to.

Where the panel is inherited (above), its existing mounting holes win — a v2.2-era panel with
round Ø3.2 holes keeps them.

## The wordmark

**The mark names who designed the module.**

| the design is | the panel says |
|---|---|
| mine, original | `MISSING MILE MODULAR` — `MMM` where the width does not allow it |
| a port or revision of someone else's | that maker's name — `KASSUTRONICS`, `KT` on 4 HP |
| this precision adder | `508`, which is what the built v2.2 panel carries, kept for continuity |

Whatever the word, it is letterspaced inside a plain two-lead component frame — the same
schematic-fragment idea as RYO's, a different part. It sits at `height − 7.0`, above the
mounting line, because a 6.4 mm slot leaves only 17.8 mm between the bottom pair and a full
wordmark needs 19.0. At 4 HP the bottom margin has only ~7 mm of clear width, which is what
the short forms are for.

## Screw holes

3.4 mm holes fix the board behind the panel. They are drilled and then ignored: they need no
layout entry, take no label and get no marks. Mounting slots are treated the same way.

## The star-field

Off. The reference's scatter reads as texture because it covers a whole panel edge to edge;
here, once the keepouts around holes, wires, brackets and type have taken their share, there
is nothing left but orphans — measured, 15 of 17 survivors on Slope had no near neighbour,
and the ASR had none at all. An orphan dot reads as fab dirt. The travel rings already carry
the polar-dot language.

It stays available, and a panel that turns out to have real open space can opt back in.

## Per-module cases

Rules that exist for one panel and are recorded so they are not mistaken for house style.

**The Kassutronics Quantizer's glyphs.** Its shift layer is iconographic, and those icons are
what its user manual teaches, so they are redrawn rather than replaced with words — twelve of
them, each built in a local box running -1..1 from the same strokes and arcs as everything
else and scaled on placement:

| button | glyph | function |
|---|---|---|
| 0 | `gate_length` | gate length — a crotchet and a minim, a short note and a long one |
| 1 | `rotate` | rotate menu |
| 2 / 3 | `transpose_both` / `transpose_one` | transpose |
| 4 / 5 | `offset_both` / `offset_one` | offset |
| 6 | `keyboard` | keyboard mode |
| 7 | `legato` | legato — two crotchets under a slur |
| 8 | `gear` | settings |
| 9 | `tau` | gate length |
| 10 / 11 | `cv_a` / `cv_b` | CV A / CV B menus |

The "both channels" glyphs carry two marks where the "one channel" ones carry one — the
distinction the original draws, and the one the manual describes. `tau` is drawn rather than
set, so it cannot depend on the stroke font carrying Greek.

**The keyboard ring inverts.** The original fills the five *black* keys as wedges on a white
panel. Straight onto black soldermask that reading breaks, so the seven **white** keys are
filled instead and the black keys are left as bare panel — same keyboard, same contrast,
opposite ink. Adjacent white keys (E–F, B–C) merge into one shape, as on a real keyboard.
Each wedge subtracts its own scale button's hole with clearance rather than printing over it.
The numbers moved outside the keyboard ring to make room, and **3 and 9 are omitted** — they
sit dead on the panel edges, exactly as on the original.

## Checking a panel

For a generated panel, start from a stub with every hole classified by diameter and each
label `TODO`; the build skips any layout still containing `TODO`.

```sh
python3 tools/panel_compose.py --stub documentation/Foo/Foo.panel.json
```

Then, in this order, however the panel was made:

1. **every control matched and every hole accounted for** — no unmatched control, no
   unaccounted hole;
2. **hole positions identical to the board's.** Compare against the drill file, not against
   the last drawing;
3. **no collisions.** For a KiCad panel, `kicad-cli pcb drc` reports **zero** violations —
   not "warnings only", since the keepouts are under our control and anything surviving is
   real. For a drawn panel, print at 100%, check the sheet measures what the drawing claims,
   and check clearance on anything unproven by an existing build;
4. **rasterise it and look at it.**

## Versioning

**Any change to this document increments the version by one hundredth** — v1.02 → v1.03 →
v1.04, and so on. There is no distinction between a typo and a new rule; every edit is a
bump.

Two things move together, and a change that touches only one of them is incomplete:

1. the version line at the top of this file;
2. the filename — `PANEL_STYLE_v1.02.md` → `PANEL_STYLE_v1.03.md`. Rename with `git mv` so
   the history follows the file.

Then update anything pointing at the old filename (`README.md`).

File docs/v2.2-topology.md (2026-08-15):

# v2.2 circuit, transcribed

Read off [`reference/Schematic_precision-adder-final-v2.2.pdf`](../reference/Schematic_precision-adder-final-v2.2.pdf) (EasyEDA, rev 2.2, 2020-10-25, drawn by
rossgrady, 508 Loop Detected) so a redraw does not mean squinting at the PDF. The design is
someone else's; this is a transcription for reference, not a claim on it.

The PDF is a vector export with no netlist in it, so nothing can convert it to a KiCad
schematic automatically — a PDF holds line segments that happen to touch, not connectivity.
What follows is the connectivity, read by eye and checked against the BOM designators.

## The idea in one line

A trimmed **±2.5 V reference pair** is the only precision source on the board. Each stage
picks one polarity of it with an SPDT, scales it down to that stage's interval with a
resistor divider, buffers it, and adds it to the stage's input at unity gain.

```
 ±12V ─→ ±5V (78L05/79L05) ─→ ±2.5V refs (OPA2196 + trimmers)
                                    │
              SPDT picks + or −  ───┤
                                    ↓
   INn ─→ buffer ─→┐        divider (fixed R + 1k trim) ─→ buffer ─→┐
                   ├──── two 10k into a summing node ───────────────┤
                   ↓                                                ↓
                 non-inverting amp, gain 2  ─────────────────────→ OUTn
   INn ─→ buffer ────────────────────────────────────────────────→ PTn
```

Gain 2 undoes the ÷2 of summing through two equal resistors, so `OUT = IN + Vbias` exactly.

## One stage, by designator

Stage 1 shown; the other three are identical but for the divider values and the op-amp
package. Four channels per stage, one quad each: `U1`–`U4` for stages 1–4.

| Block | Connectivity |
|---|---|
| Divider | `Vref1` → `R5` 10k → `VR1` 1k trimmer → `R4` 40k → GND. Wiper → `U1.1` pin 3 (+) |
| Ref buffer | `U1.1` pin 2 (−) tied to pin 1 (out), `C5` 22p across it. Unity gain |
| Damping | `U1.1` out → `R24` 619R → `C30` 330p → GND |
| Input buffer | `IN1` → `U1.2` pin 5 (+); pin 6 (−) tied to pin 7 (out) |
| Summing node | `U1.2` out → `R19` 10k → node; `U1.1` out → `R28` 10k → same node; node → `U1.3` pin 10 (+) |
| Output amp | `U1.3` pin 9 (−) ← `R21` 10k to GND, `R20` 10k feedback from pin 8. Gain 2. Pin 8 = `OUT1` |
| Passthru | `IN1` → `U1.4` pin 12 (+); pin 13 (−) tied to pin 14 (out) = `PT1` |

Per-stage dividers, all fed from ±2.5 V. The trimmer sets the final value; the fixed pair
sets the range around it.

| Stage | Target | Top R | Trim | Bottom R | Nominal |
|---|---|---|---|---|---|
| 1 | 2 V (2 oct) | `R5` 10k | `VR1` 1k | `R4` 40k | 1.961 – 2.010 V |
| 2 | 1 V (1 oct) | `R6` 15k | `VR2` 1k | `R7` 10k | 0.962 – 1.058 V |
| 3 | 0.583333 V (5th) | `R11` 50k | `VR3` 1k | `R10` 15k | 0.568 – 0.587 V |
| 4 | 0.416667 V (4th) | `R9` 50k | `VR4` 1k | `R8` 10k | 0.410 – 0.451 V |

## References and power

| Block | Connectivity |
|---|---|
| Supply | `P1` 2×5 IDC → `F1`/`F2` ferrites, `D6`/`D7` 1N5817 reverse protection, `C15`/`C16` 10u, `C20`/`C21` 100p |
| +5 V | `U5` 78L05, `C2` 0.33u in, `C3` 0.01u out |
| −5 V | `U6` 79L05, `C7` 0.33u in, `C6` 0.1u out |
| +2.5 V ref | +5 V → `R30` 50k → `VR5` 50k → `R31` 50k → GND; wiper → `U9` pin 3, buffered on pin 1, `C1` 10u |
| −2.5 V ref | −5 V → `R1` 50k → `VR6` 50k → `R13` 50k → GND; wiper → `U9` pin 5, buffered on pin 7, `C9` 10u, `C12` 0.1u |

## Board split

Two boards. `H1`–`H4` (male) mate with `H6`, `H8`–`H10` (female), each carrying one stage's
`OUTn` / `Vrefn` / `INn` / `PTn`. `H5`/`H7` (1×3) carry `+2.5V Ref`, `−2.5V Ref`, GND to the
front board. The switches `G$1`–`G$4` live on the front board and only ever route a
reference, never a signal — which is why the switch carries no audio-path current and its
contact resistance does not matter.

Op-amp budget: 4 channels × 4 stages = 16 (`U1`–`U4`, OPA4196 quads) + 2 for the references
(`U9`, OPA2196 dual) = 18, matching the BOM.

## What v3 changes

Proposal, not yet drawn. The reference block, the power block and the summing topology carry
over unchanged — that is the proven part and it is a small fraction of the sheet.

**Drops.** `IN2`–`IN4` and `PT2`–`PT4` go, and with them the per-stage passthru buffers
(`U*.4`, 4 channels) and the input buffers on stages 2–4 (3 channels) — a cascaded stage is
fed from the previous stage's output, which is already low impedance.

**Adds.** A three-input summing amp at the front for `IN1`+`IN2`+`IN3`, and a buffer for
`SUM`. Roughly 10 channels total against v2.2's 18, so three quads become two, or two quads
plus the existing dual.

**The one new problem.** Each stage now needs *three* selectable magnitudes rather than one,
chosen by the `ON-ON-ON` selector. Three separate dividers per stage would mean twelve
trimmers. A single tapped ladder does it with one, because the taps are ratios of the same
chain and the op-amp inputs draw nothing, so selecting a tap does not disturb the others —
and one trimmer in series scales all three together.

Chains below are shown as segments from GND upward, on a 30k total, all from the same ±2.5 V:

| Stage | Segments (GND → Vref) | Taps |
|---|---|---|
| 1 `OCT` | 12k, 12k, 6k | 12k → 1.000 V (1 oct), 24k → 2.000 V (2 oct) |
| 2, 3 `3RD` | 3k, 1k, 1k, 25k | 3k → 0.250 V (m3), 4k → 0.333333 V (M3), 5k → 0.416667 V (4th) |
| 4 `5TH` | 3k, 1k, 3k, 23k | 3k → 0.250 V (m3), 4k → 0.333333 V (M3), 7k → 0.583333 V (5th) |

The trimmer sits in series at the top of the chain, so it scales every tap together and
absorbs the top segment's absolute value — meaning **only the segments below the taps need
to be precise**. The top segment can be the nearest E96 part. What matters is the ratio
between the small segments (1k, 3k, 12k), and that is where hand-matched parts earn their
keep. The top segment is drawn 0.5k light so the chain is nominal with the trimmer centred,
giving about ±1.7% either way.

At E96 the worst case on a ratio-defining segment is about 0.3%, which on a 0.25 V minor
third is 0.75 mV — **under one cent**. Ordinary 0.1% parts are comfortable and even 1%
would likely pass.

This is drawn: [`v3-adder.kicad_sch`](v3-adder.kicad_sch), from
[`../tools/gen_schematic.py`](../tools/gen_schematic.py).

Also unresolved, carried from the README: headroom with three summed inputs plus up to
±3.42 octaves of offset on a ±12 V supply, and matching on the three input summing resistors.

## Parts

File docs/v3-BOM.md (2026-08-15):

# v3 bill of materials

Built for **hand assembly**: 1206 everywhere an SMD part is used, and through-hole kept for
anything that was already through-hole. 1206 is the largest size these values are commonly
stocked in, and the OPA4196's SOIC-14 is the largest package it comes in.

101 components. Values verified against the ladder maths in `v2.2-topology.md` — every
interval tap lands **exact to 0.000 cents** with these parts.

## Resistors

All 1206, `Resistor_SMD:R_1206_3216Metric`.

### 0.1 % — 32 parts

These set pitch directly. The per-stage trimmer corrects the chain's overall scale but
**not the ratios between taps**, so tolerance here is not recoverable.

| Qty | Value | Designators | Role |
|---:|---|---|---|
| 20 | 10.0k | R5–R7, R9, R15–R18, R25–R28, R35–R38, R45–R48 | input summing, per-stage summing and ×2 gain pairs |
| 5 | 1.00k | R21, R22, R31, R32, R41 | ladder segments |
| 4 | 3.00k | R20, R30, R40, R42 | ladder bottom segments |
| 2 | 12.0k | R11, R12 | `OCT` ladder — **match these two to each other** above all |
| 1 | 20.0k | R8 | input summer gain, ratio with R9 |

**3.00k and 12.0k are E24, not E96, and that is deliberate.** E96 has no exact 3:1 pair —
its nearest is 3.01k against 1.00k, which is a 0.33 % ratio error and puts the 4th out by
0.66 cents. Worse, that error cannot be selected away: a 0.1 % 3.01k never measures 3.000k.
E24 values are stocked in 0.1 % thin film, so use them.

`OCT` only needs its two segments **equal to each other** — the absolute value is free,
because the trimmer sets the scale and the second tap is twice the first by construction.
A matched pair matters more than the marked value.

### 1 % is fine — 17 parts

| Qty | Value | Designators | Why tolerance does not matter |
|---:|---|---|---|
| 5 | 1.00k | R10, R19, R29, R39, R49 | output series protection |
| 4 | 49.9k | R1–R4 | reference dividers — trimmed by VR5/VR6 |
| 4 | 619R | R14, R24, R34, R44 | buffer output snubbers |
| 2 | 24.3k | R23, R33 | ladder top, absorbed by trim |
| 1 | 22.6k | R43 | ladder top, absorbed by trim |
| 1 | 5.49k | R13 | ladder top, absorbed by trim |

## Capacitors

| Qty | Value | Type | Designators | Footprint |
|---:|---|---|---|---|
| 7 | 0.1uF | X7R | C8, C11–C16 | `Capacitor_SMD:C_1206_3216Metric` |
| 4 | 330pF | C0G | C17–C20 | `Capacitor_SMD:C_1206_3216Metric` |
| 2 | 10uF | electrolytic, **ESR ≥1 Ω, mount lying flat** | C9, C10 | `Capacitor_THT:CP_Radial_D5.0mm_P2.00mm` |
| 2 | 10uF | electrolytic, any height, mounts upright | C1, C3 | `Capacitor_THT:CP_Radial_D5.0mm_P2.00mm` |
| 2 | 0.33uF | X7R | C5, C7 | `Capacitor_SMD:C_1206_3216Metric` |
| 2 | 100pF | C0G | C2, C4 | `Capacitor_SMD:C_1206_3216Metric` |
| 1 | 0.01uF | X7R | C6 | `Capacitor_SMD:C_1206_3216Metric` |

C0G on the snubbers and the HF supply caps; X7R elsewhere is fine.

**C9 and C10 must be low-profile cans; C1 and C3 need not be.** The two boards
are stacked, and the only parts inside the gap are the ones on the control
board's rear face — which is where C9 and C10 live. C1 and C3 sit on the trimmer
board's rear, facing the back of the case, where nothing constrains them.

The gap is set by the interconnect: an 8.50 mm socket body plus the 2.54 mm
plastic of the mating header puts the two boards **11.04 mm** apart. That is the
whole budget for anything on the control board's rear, and the parts already
there use:

| | height above board |
|---|---|
| U4, U5 — TO-92 | 7.30 mm |
| C9, C10 — as modelled | 5.00 mm |
| U1–U3 — SOIC-14 | 1.75 mm |
| 1206 SMD | ~0.95 mm |

A 5 mm-diameter 10 µF is sold as a **5 × 11 mm** can, and 11 mm against 11.04 mm
is no clearance at all — stood upright it will foul the trimmer board. There is
no shorter part to buy; every stocked 5 mm 10 µF is 11 mm or longer.

**So C9 and C10 are laid flat**, leads bent 90° at the board, the can resting on
the control board's rear face. On its side the same part is 5.00 mm tall — the
figure in the table above — which leaves 6 mm of clearance. Anything up to 7 mm
is safe; past that the margin is not worth having.

### C9 and C10 need ESR, and "low ESR" is the wrong part

They hang directly off U3's reference buffer outputs, wired as unity-gain
followers — the worst case for capacitive load. **The OPA4196 is rated to drive
1 nF bare. These are 10 µF, ten thousand times that.** The capacitor's own ESR is
what keeps that loop stable, so it is a specified parameter here, not a defect to
be minimised.

TI's Table 3 (SBOS869) gives the series resistance needed for a given phase
margin, and stops characterising at 1 µF:

| C load | 100 pF | 1 nF | 10 nF | 100 nF | 1 µF |
|---|---|---|---|---|---|
| R for 45° | 280 Ω | 113 Ω | 68 Ω | 17.8 Ω | 3.6 Ω |
| R for 60° | — | 432 Ω | 210 Ω | 53.6 Ω | 10 Ω |

Extrapolating one decade puts 10 µF at roughly **0.8 Ω for 45° and 2.2 Ω for
60°**. Against what each capacitor type actually offers:

| Type, 10 µF | ESR | |
|---|---|---|
| ceramic X7R 1210 | 2–10 mΩ | ~200× too low |
| polymer tantalum, polymer aluminium | 20–100 mΩ | still far too low |
| **MnO2 tantalum, EIA-3528** | 0.5–3 Ω | in range |
| **aluminium electrolytic, 5 mm** | 1–3 Ω | in range |

So **do not substitute a ceramic, a polymer tantalum, or a "low ESR" aluminium
part here.** All three are marketed as upgrades and all three remove the damping.
An ordinary aluminium electrolytic — the last row of that table, and what the
board's through-hole footprint expects — sits squarely in range. Height is dealt
with by laying the can flat, as above, not by picking a different chemistry.

The ESR must be in the capacitor rather than a discrete resistor, even though TI
recommends the resistor. An isolation resistor sits between the amplifier output
and *everything*, so the ladder current flows through it: worst case is four
30 kΩ ladders selecting the positive reference, 333 µA. At the 10 Ω TI lists for
1 µF that is 3.3 mV of reference shift, moving the `OCT_2V` tap by 3.2 cents —
and the shift tracks how many switches point up, so it is not a fixed offset and
cannot be trimmed out. The capacitor's ESR carries no DC load current at all,
because the ladders connect to the amplifier output directly.

## Semiconductors

| Qty | Part | Designators | Footprint |
|---:|---|---|---|
| 3 | OPA4196 (SOIC-14) | U1, U2, U3 | `Package_SO:SOIC-14_3.9x8.7mm_P1.27mm` |
| 1 | L78L05 | U4 | `Package_TO_SOT_THT:TO-92_Inline` |
| 1 | L79L05 | U5 | `Package_TO_SOT_THT:TO-92_Inline` |
| 2 | 1N5819 | D1, D2 | `Diode_THT:D_DO-41_SOD81_P10.16mm_Horizontal` |

**The two regulators do not share a pinout.** L78L05 TO-92 is `1 = VOUT, 2 = GND, 3 = VIN`;
L79L05 is `1 = GND, 2 = VIN, 3 = VOUT`. Both datasheet figures are *bottom* views — check
the footprint's pad 1 against the datasheet with the part oriented as you will fit it.

## Electromechanical

| Qty | Part | Designators | Footprint |
|---:|---|---|---|
| 8 | Thonkiconn PJ398SM | J1–J8 | `eurorack:Thonkiconn_PJ301M` |
| 4 | Taiway `200-MSP3-T1B1M2QE` SPDT ON-OFF-ON | SW1–SW4 | `eurorack:SW_Taiway_200_SPDT` |
| 3 | Taiway `200-MDP6-T1B1M2QE` DPDT ON-ON-ON | SW6, SW7, SW8 | `eurorack:SW_Taiway_200_DPDT` |
| 1 | Taiway `200-MSP1-T1B1M2QE` SPDT ON-ON | SW5 | `eurorack:SW_Taiway_200_SPDT` |
| 4 | 1k multiturn trimmer | VR1–VR4 | `Potentiometer_THT:Potentiometer_Bourns_3296W_Vertical` |
| 2 | 50k multiturn trimmer | VR5, VR6 | `Potentiometer_THT:Potentiometer_Bourns_3296W_Vertical` |
| 2 | Ferrite bead, axial | FB1, FB2 | `Resistor_THT:R_Axial_DIN0207_L6.3mm_D2.5mm_P7.62mm_Horizontal` |
| 1 | Eurorack 2×5 shrouded header | P1 | `Connector_IDC:IDC-Header_2x05_P2.54mm_Vertical` |
| 4 | 1×6 pin header, 2.54 mm | P2–P5 | `Connector_PinHeader_2.54mm:PinHeader_1x06_P2.54mm_Vertical` |
| 4 | 1×6 socket, 2.54 mm | P6–P9 | `Connector_PinSocket_2.54mm:PinSocket_1x06_P2.54mm_Vertical` |

Keep the **shrouded, keyed** power header — it is the only thing that stops the ribbon
going on backwards, and D1/D2 are the last line of defence after it.

### Board-to-board interconnect

P2–P9 join the two cards. Pins go on the **control board's rear**, sockets on the
**trimmer board's front**, and the cards stack by a plain 20.2 mm translation with
no flip. Mating pairs:

| Pins (control board) | Socket (trimmer board) | 1 | 2 | 3 | 4 | 5 | 6 |
|---|---|---|---|---|---|---|---|
| P2 | P6 | GND | REFP_TOP | — | — | — | +12V |
| P3 | P7 | GND | LAD1_TOP | LAD2_TOP | S2_4th | LAD1_TRIM | −12V |
| P4 | P8 | +12V | REFP_W | — | REFN_TOP | LAD3_TOP | GND |
| P5 | P9 | S4_5th | S3_4th | LAD4_TOP | REFN_W | — | GND |

Nineteen signals across twenty-four pins; the five dashes are spares, carried in the
schematic as no-connects so they stay available. The socket body is what sets the
11.04 mm board spacing the capacitor heights are budgeted against, so substituting a
taller or shorter socket changes that budget.

### Footprint libraries

Everything resolves against stock KiCad libraries plus `eurorack.pretty` at the repo root,
wired up by `docs/fp-lib-table` as `${KIPRJMOD}/../eurorack.pretty`. **ERC reports 0 errors
and 0 warnings.**

Two footprints were added to `eurorack.pretty` for this build:

| Footprint | Notes |
|---|---|
| `SW_Taiway_200_SPDT` | 3 pads in a line on 2.54, **pad 2 is the common** |
| `SW_Taiway_200_DPDT` | 6 pads, 2.54 × 5.08, **pads 2 and 5 are the commons** |

**Both use Taiway's own pin numbering.** The library already contained
`SW_200_MDP3_DPDT`, which is the same physical part with the commons deliberately remapped
to pads 1 and 4 to suit a differently-numbered symbol. The two are *not* interchangeable —
pick the one matching your symbol and confirm the common lands on a centre terminal. Both
descriptions say so.

The Thonkiconn footprint names its pads `T` / `TN` / `S` rather than 1/2/3, so the jack
symbols use those as their pin numbers. KiCad allows any string there, and matching the
footprint is what keeps the pads connected.

Panel holes for the toggles are Ø5.0, against Taiway's recommended Ø4.95 for the 10‑48
bushing — fine. The optional 4.55 mm anti-rotation flat is not cut, so nut torque alone
holds them.

### Switch designators

`SW1`–`SW4` are the four polarity toggles, one per stage. `SW5` is the `OCT` magnitude
switch. `SW6`–`SW8` are the three quality selectors on stages 2–4.

Earlier drafts called these `SW1A`/`SW1B` and so on. That reads well but KiCad rejects it:
a trailing letter is how it writes the *unit* of a multi-unit symbol, so a reference ending
in one never counts as annotated. It does not appear in ERC — only in the annotation dialog
and as a warning on netlist export.

## Trimmer set points

Each chain totals **30k** when correctly trimmed. Nominal wiper settings, all comfortably
mid-travel on a 1k part:

| Trimmer | Stage | Fixed top | Trim to |
|---|---|---:|---:|
| VR1 | `OCT` | 5.49k | ~510 Ω |
| VR2, VR3 | `3RD` | 24.3k | ~700 Ω |
| VR4 | `5TH` | 22.6k | ~400 Ω |

The trim only has to absorb resistor tolerance — about ±60 Ω on a 30k chain at 0.1 % — so a
1k part is roughly eight times the range needed. VR5/VR6 set the ±2.5 V references and are
the first thing to adjust; everything else is a ratio of them.

## Changes from what is currently in the schematic

Apply with **Tools → Edit Symbol Fields** in Eeschema — it bulk-edits Value and Footprint by
group.

| Was | Now | Parts |
|---|---|---|
| 0805 | 1206 | every SMD R and C |
| 3k | 3.00k | R20, R30, R40, R42 |
| 12k | 12.0k | R11, R12 |
| 5.5k | 5.49k | R13 |
| 24.5k | 24.3k | R23, R33 |
| 22.5k | 22.6k | R43 |
| 50k | 49.9k | R1–R4 |

Only the first is a real change of part; the rest are non-stock values being pinned to
stocked ones. None of them alters a tap voltage — the trimmer takes up the difference.

**This table is history, and its first two rows now read backwards.** The Value fields were
later shortened for the silkscreen, so the schematic and board say `3k` and `12k` again. The
parts did not change back: they are still the E24 3.00 k and 12.0 k 0.1 % resistors chosen
above, and the reasoning for picking E24 over E96 stands. Only the label is shorter. Trailing
zeros are dropped wherever they carry no information — `10.0k` is written `10k`, while `49.9k`,
`24.3k`, `22.6k` and `5.49k` keep every digit. Tolerance lives in this document, not on the
silk, which has no room for it at 4 HP.

## Sourcing

[`BOM_v3_DigiKey.csv`](BOM_v3_DigiKey.csv) is an upload-ready DigiKey list covering 93 of the
parts. Create a list at [digikey.com/en/mylists](https://www.digikey.com/en/mylists) and choose
the spreadsheet upload option. Every line was checked as Active and in stock on 2026-08-14
except where noted below; stock moves, so verify before ordering.

**Reconciled against the board** on 2026-08-15. `v3-adder.kicad_pcb` places 109 footprints. The
CSV's 93 pieces plus the 13 parts listed under *Not on the DigiKey list* below account for 106 of
them; the remaining 3 are P2–P5, which the board draws as four separate 1×6 headers and the CSV
buys as a single 1×40 breakaway strip. Every value and quantity in the tables above matches the
board exactly.

### Resistors

**The E24 gamble paid off.** Panasonic's ERA-8 series carries 0.1 % thin film in 1206 across
both E24 values this design depends on — `ERA-8AEB302V` for the 3.00k and `ERA-8AEB123V` for
the 12.0k — with 18.5k and healthy stock respectively. The argument above for choosing E24
over E96 therefore costs nothing in availability, which was the one thing that could have
undermined it. All five 0.1 % values come from the same series, so they share a tolerance
grade, a tempco (±25 ppm/°C) and a supplier.

The 1 % parts are Yageo RC1206 except the 49.9k. Yageo's `RC1206FR-0749K9L` is out of stock
with a restock date of 2026-08-17, and Panasonic's `ERJ-8ENF4992V` — the obvious substitute —
is marked **Not For New Designs**, which is the wrong flag for a board that has not been built
yet. The list uses Vishay `CRCW120649K9FKEA` instead: active, in stock, same price.

The 1.00k appears twice, five at 0.1 % (ladder segments) and five at 1 % (output protection).
That split is deliberate and follows the tolerance reasoning above. If you would rather buy one
part than two, ordering all ten as `ERA-8AEB102V` is never wrong — it costs about $0.85 extra.

### C9 and C10 — resolved: electrolytic, laid flat

Earlier revisions of this section argued for an MnO2 tantalum in EIA-3528, which conflicts with
the footprint. `v3-adder.kicad_pcb` places all four 10 µF positions — C1, C3, C9 and C10 — on the
same `CP_Radial_D5.0mm_P2.00mm` through-hole footprint, so the board wants a can, not a chip.
**All four are ordinary aluminium electrolytics: Panasonic `ECA-1VM100`, 10 µF 35 V, 5 mm
diameter on 2 mm pitch.** No board edit, and one line on the order instead of two.

This satisfies the stability requirement on its own terms. The table above puts a 5 mm aluminium
electrolytic at 1–3 Ω of ESR, which is the range the phase-margin analysis calls for — the same
row that made the tantalum acceptable. Nothing about the damping argument changes.

**Height is handled by mounting, not by part selection.** A 5 mm 10 µF can is 5 × 11 mm, and
11 mm against an 11.04 mm board gap is no clearance at all. So **lay C9 and C10 over** — bend the
leads 90° at the board and let the cans lie against the control board's rear face. A 5 mm-diameter
can on its side stands 5.00 mm, which is exactly the figure the height table above already
budgets for C9/C10, so the design's own numbers assume this. Allow about 12 mm of clear board
length next to each one for the body to lie in, and orient them away from U4/U5.

C1 and C3 mount normally. They sit on the trimmer board's rear, facing the back of the case,
where nothing constrains height.

There is no shorter part to buy instead: DigiKey's stocked 5 mm-diameter 10 µF through-hole parts
start at 5 × 11 mm and run to 5 × 13 mm. Dropping the voltage rating does not shrink the can at
this capacitance either.

### OPA4196 packaging

`OPA4196IDR` (tape) is out of stock until 2026-09-08. The list uses `OPA4196ID` (tube) at
$5.36 against the reel part's $4.55. Three of them either way, so the packaging premium is
about $2.40 — cheaper than waiting, and the tube is easier to handle for hand assembly anyway.

### Not on the DigiKey list

| Qty | Part | Why | Where |
|---:|---|---|---|
| 8 | Thonkiconn PJ398SM | Not a DigiKey line | Thonk, Modular Addict |
| 3 | Taiway `200-MDP6-T1B1M2QE` DPDT ON-ON-ON | See below | Tayda, Love My Switches, Small Bear |
| 2 | Ferrite bead, axial leaded | See below | Mouser, or substitute |

**The ON-ON-ON DPDT has no DigiKey equivalent.** The three quality selectors are the one switch
function DigiKey cannot supply in this form factor: its only stocked ON-ON-ON DPDT is a full-size
part with a 15/32-32 bushing and a right-angle body, and it is not kept in stock either. The
sub-miniature 10-48 part has to come from a synth DIY shop. The other five switches are fine —
E-Switch `200MSP3T2B1M2QE` (ON-OFF-ON) and `200MSP1T1B1M2QEH` (ON-ON) are both stocked, in the
same 10-48 sub-miniature family, and drop onto the Taiway footprints.

Note the suffix: Taiway's part is `T1B1M2QE`, the stocked E-Switch ON-OFF-ON is `T2B1M2QE`.
The digit is the actuator variant, not the function or the bushing. Check the actuator length
suits your panel before committing to four of them.

**Axial ferrite beads are effectively not a DigiKey category.** They stock SMD beads and cable
cores, not the resistor-shaped leaded part the `R_Axial_DIN0207` footprint expects. Mouser
carries Würth's leaded range. Failing that, the footprint takes any 1/4 W axial body, so a wire
link or a small-value resistor will complete the board — you lose the HF filtering on the supply
rails and nothing else.

### Cost

The 0.1 % resistors and the three OPA4196 dominate: roughly $9 of precision resistors and $16 of
op amps, against about $4 for every 1 % resistor and ceramic on the board. The six trimmers add
another $14. That distribution is the design working as intended — the money is in the parts that
set pitch and in the amplifier driving them.

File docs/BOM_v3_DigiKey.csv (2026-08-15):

Quantity | Part Number | Customer Reference | Description
20 | ERA-8AEB103V | R 10k 0.1% | RES 10.0K OHM 0.1% 1/4W 1206 THIN FILM - PITCH SETTING
5 | ERA-8AEB102V | R 1k 0.1% | RES 1.00K OHM 0.1% 1/4W 1206 THIN FILM - LADDER SEGMENT
4 | ERA-8AEB302V | R 3k 0.1% | RES 3.00K OHM 0.1% 1/4W 1206 THIN FILM - E24 LADDER BOTTOM
2 | ERA-8AEB123V | R 12k 0.1% | RES 12.0K OHM 0.1% 1/4W 1206 THIN FILM - E24 OCT LADDER MATCHED PAIR
1 | ERA-8AEB203V | R 20k 0.1% | RES 20.0K OHM 0.1% 1/4W 1206 THIN FILM - INPUT SUMMER GAIN
5 | RC1206FR-071KL | R 1k 1% | RES 1.00K OHM 1% 1/4W 1206 - OUTPUT SERIES PROTECTION
4 | CRCW120649K9FKEA | R 49k9 1% | RES 49.9K OHM 1% 1/4W 1206 - REFERENCE DIVIDER TRIMMED
4 | RC1206FR-07619RL | R 619R 1% | RES 619 OHM 1% 1/4W 1206 - BUFFER OUTPUT SNUBBER
2 | RC1206FR-0724K3L | R 24k3 1% | RES 24.3K OHM 1% 1/4W 1206 - LADDER TOP ABSORBED BY TRIM
1 | RC1206FR-0722K6L | R 22k6 1% | RES 22.6K OHM 1% 1/4W 1206 - LADDER TOP ABSORBED BY TRIM
1 | RC1206FR-075K49L | R 5k49 1% | RES 5.49K OHM 1% 1/4W 1206 - LADDER TOP ABSORBED BY TRIM
7 | C1206C104K5RACTU | C 0.1uF | CAP CER 0.1UF 50V X7R 1206 SMD
4 | C1206C331J5GACTU | C 330pF | CAP CER 330PF 50V C0G NP0 1206 SMD
2 | C1206C334K5RACTU | C 0.33uF | CAP CER 0.33UF 50V X7R 1206 SMD
2 | C1206C101J5GACTU | C 100pF | CAP CER 100PF 50V C0G NP0 1206 SMD
1 | C1206C103K5RACTU | C 0.01uF | CAP CER 0.01UF 50V X7R 1206 SMD
4 | ECA-1VM100 | C 10uF C1 C3 C9 C10 | CAP ALUM 10UF 35V RADIAL 5MM DIA 2MM PITCH - LAY C9 AND C10 FLAT
3 | OPA4196ID | IC OPA4196 | IC OPAMP QUAD RAIL-TO-RAIL 14-SOIC TUBE
1 | L78L05ACZ | IC 78L05 | IC REG LINEAR 5V 100MA TO-92
1 | L79L05ACZ | IC 79L05 | IC REG LINEAR -5V 100MA TO-92
2 | 1N5819-T | D 1N5819 | DIODE SCHOTTKY 40V 1A DO-41 THROUGH HOLE
4 | 3296W-1-102LF | RV 1k TRIM | TRIMMER 1K OHM 25 TURN TOP ADJUST PC PINS
2 | 3296W-1-503LF | RV 50k TRIM | TRIMMER 50K OHM 25 TURN TOP ADJUST PC PINS
4 | 200MSP3T2B1M2QE | SW1-SW4 SPDT | SWITCH TOGGLE SPDT ON-OFF-ON 10-48 BUSHING PC PIN
1 | 200MSP1T1B1M2QEH | SW5 SPDT | SWITCH TOGGLE SPDT ON-ON 10-48 BUSHING PC PIN
1 | SBH11-PBPC-D05-ST-BK | P1 POWER | CONN HEADER SHROUDED 2X5 2.54MM EURORACK POWER KEYED
1 | PRPC040SAAN-RC | P2-P5 PINS | CONN HEADER 1X40 2.54MM BREAKAWAY - SNAP INTO 4X 1X6
4 | PPTC061LFBN-RC | P6-P9 SKT | CONN HEADER FEMALE 1X6 2.54MM - 8.51MM BODY SETS BOARD SPACING

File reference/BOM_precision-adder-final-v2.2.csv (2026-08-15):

ID | Name | Designator | Footprint | Quantity | Source
1 | 100pF | C20,C21 | C0805 | 2
2 | THONKICONNNEW | PT3,PT1,IN2,OUT2, OUT1,PT4,IN4,OUT4, PT2,IN3,OUT3,IN1 | THONKICONN-TIGHT | 12 | Thonk or Tayda
3 | L79L05ACZ | U6 | TO-92-3_L4.8-W3.7-P2.54-L | 1
4 | 1k | VR1,VR4,VR2,VR3 | PV36W-MULTITURN-TRIMMER | 4
5 | 10k | VR5,VR6 | PV36W-MULTITURN-TRIMMER | 2
6 | Ferrite | F2,F1 | 7MM_RESISTOR | 2
7 | 10k 0.1% | R12,R16,R20,R21, R14,R17,R7,R19, R29,R28,R27,R18, R3,R8,R2,R26, R25,R23,R5 | R0805 | 19
8 | 50k | R13,R1,R11,R31,R30,R9 | R0805 | 6
9 | 15k | R6,R10 | R0805 | 2
10 | 40k | R4 | R0805 | 1
11 | 619R | R32,R24,R22,R15 | R0805 | 4
12 | SUBMINI_SPDT ON-ON | G$1,G$2,G$3,G$4 | SUBMINI_TOGGLE | 4 | Thonk
13 | 0.1uF | C17,C14,C13,C6, C18,C12,C11,C26, C25,C24,C23,C22,C19 | C0805 | 13
14 | 0.33uF | C7,C2 | C0805 | 2
15 | 0.01uF | C3 | C0805 | 1
16 | 22pF | C4,C27,C5,C28 | C0805 | 4
17 | 330pF | C30,C10,C29,C8 | C0805 | 4
18 | IDC Box 2.54mm 2X5P | P1 | EURO_PWR_HEADER_LOCK | 1
19 | HDR-F-2.54_1x3 | H7 | HDR-F-2.54_1X3 | 1
20 | HDR-M-2.54_1x3 | H5 | HDR-F-2.54_1X3 | 1
21 | 1N5819 | D6,D7 | DO-41 | 2
22 | 10uF | C1,C9, C15, C16 | CAP-D5.0XF2.0 | 4
24 | HDR-M-2.54_1x4 | H1,H3,H2,H4 | HDR-F-2.54_1X4 | 4
25 | HDR-F-2.54_1x4 | H6,H10,H9,H8 | HDR-F-2.54_1X4 | 4
26 | OPA2196IDR | U9 | SOIC-8_L5.0-W3.2-P1.27-LS8.3-BL | 1
27 | L78L05ACZTR | U5 | TO-92-3_L4.8-W3.7-P2.54-L | 1
28 | OPA4196ID | U3,U2,U4,U1 | SOIC-14_150MIL | 4

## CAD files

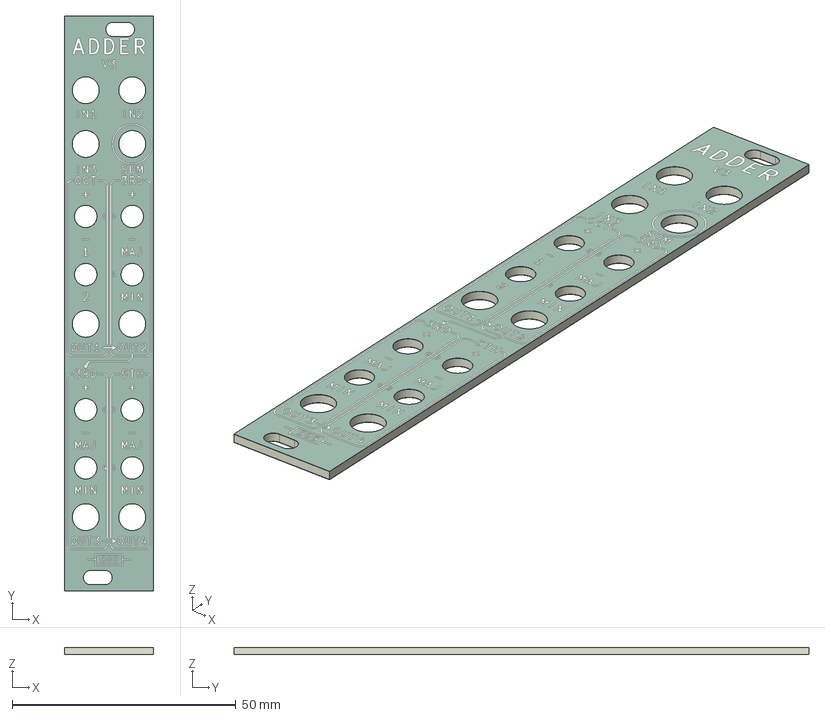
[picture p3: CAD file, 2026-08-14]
docs/panel.step
20.0 x 128.5 x 1.64 mm
v3-panel_silkscreen
v3-panel_soldermask x 2
v3-panel_PCB

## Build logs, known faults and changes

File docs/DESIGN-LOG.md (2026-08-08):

# Design log — v3, 2026-08-03

How the v3 proposal in the README was arrived at, including the options that were
rejected and why. The charts and numbers live in the README appendix; this file is
the reasoning and the dead ends, which the appendix does not record.

Raw session transcript: `docs/session-2026-08-03-v3-design.jsonl` (gitignored, local only).
Everything numeric here is reproducible with `interval-study.py`.

---

## 1. The v2.2 defect

Started by enumerating what v2.2 can actually produce. With ON-ON switches and
bypass-by-patching, four stages of `{24, 12, 7, 5}` semitones give 81 configurations
but only **39 distinct voltages**, and the reachable pitch classes are just
`{0, 2, 5, 7, 10}` — the suspended pentatonic.

Cause: **a fifth plus a fourth is exactly an octave** (7 + 5 = 12). Two of the four
stages are redundant with the octave stages. No thirds, no sixths, no tritone, no
semitones, ever.

## 2. Interval set search

Searched all 4-value sets 1..27. The mathematical optimum is **balanced ternary
`{1, 3, 9, 27}`** — each stage 3x the previous, 81 configurations producing 81
distinct voltages, every semitone from -40 to +40, zero redundancy. Provably
unbeatable: 81 states cannot cover more than 81 notes.

**Rejected on usability.** In balanced ternary, 2 octaves is `27 - 3` and a fourth
is `9 - 3 - 1`. Every setting is arithmetic in a base nobody thinks in, and the
panel cannot be read as intervals. The objection that killed it: *most people cannot
calculate semitones past an octave.*

This reframed the whole problem. Chromatic range is not the objective function —
**cost per interval you actually use** is. All complete designs average ~1.83 switch
flips across the twelve intervals; what separates them is *which* intervals get the
cheap settings. Balanced ternary spends its one-flip settings on the minor 2nd,
minor 3rd and major 6th. Named-interval sets spend them on the octave, fifth and
fourth.

## 3. Rejected mechanical options

**5-position rotary for the octave stage** (`-2 -1 0 +1 +2`). Elegant on paper: one
legible control, one hole. Killed by the side photo — the build is a two-board
sandwich with the front PCB about 10-11 mm behind the panel (set by the Thonkiconn
bushing). A panel-mount rotary is 20-25 mm deep and would crash through the front
board. Correct answer to "which control is most legible", wrong answer to "what fits".

**Keeping both octave stages.** Searched: spending two of four stages on octaves
caps the chromatic range at ±4 semitones regardless of what the other two are. The
octave stages were the problem, not the fifth and fourth.

**Adding four more stages to v2.2** (8 total, 6561 configurations). Only 167 distinct
voltages, because output range is bounded by the *sum* of stage values, which grows
linearly while configurations grow as 3^N. Past about four well-chosen stages, extra
stages buy range, not resolution.

## 4. The switch — taken from Doepfer

The A-185-2 uses **ON-OFF-ON** toggles, so a stage's off position is a center detent
rather than a patch cable. v2.2 uses ON-ON. Same footprint, essentially the same
price. This is a BOM choice, not a design constraint, and it invalidated a chunk of
earlier reasoning that had been working around the cost of patch-bypassing.

Also from the comparison: the A-185-2 is a *summer* first, with octave offsets falling
out of its +1 V input normalling. Its only non-octave path is a log pot, so **it
cannot produce an exact fifth** — which is precisely the gap this module fills.
Conversely it has an inverting output and an input attenuator, which this module
does not and cannot fake.

## 5. The normalling discovery

The README's original description — "each input cascades to the one below it if
there's no input below" — reads as input-to-input normalling. It is actually
**output-to-input**: `OUT1` normals to `IN2`, so with nothing patched `PT2` = `OUT1`,
`PT3` = `OUT2`, `PT4` = `OUT3`.

Consequence: **`PT2`-`PT4` are duplicates of the output above them**, and `IN2`-`IN4`
exist only to break the cascade — which the center-off switch now does better. Six
jacks doing the work of two. This was confirmed by the author mid-session and the
opening line of the README was corrected.

An earlier hypothesis in this session — that the passthrus were needed as buffered
mults to feed a parallel "same root to every stage" harmony mode — was wrong. That
mode does not exist by default.

## 6. The reframe: it is a chord generator

Given the cascade is the default and each `OUT` is a *running sum*, the four outputs
are **stacked intervals**. Stacking thirds is how chords are built. Three stages of
maj-or-min third produce every standard tetrad, on the outputs, simultaneously.

That is what the module is uniquely good at, and it is what the old `{octave, 5th,
4th, maj 3rd}` set could not do — fifths and fourths do not stack into chords.

Final refinement: stage 4 takes a **5th** where stages 2 and 3 take a 4th. Placement
is free for transposition (a sum does not care about order), so it was chosen on
chord grounds — stages 2-3 finish the triad, stage 4 becomes an extension selector
(m3 → 7th, M3 → maj7, 5th → add9). It also buys back the one-flip fifth.

## 7. Where it landed

Three summed inputs, four cascaded stages, 8 jacks + 8 switches = 16 panel positions,
identical to v2.2. 1715 configurations, 83 distinct voltages, fully chromatic across
±41 semitones, all 12 pitch classes, 12 chord voicings. Every v2.2 resistor divider
is reused; only the two third values are new.

## 8. Open questions

- **Headroom.** Three summed inputs plus up to ±3.42 octaves of offset can rail a
  ±12 V supply. The worst case for the intended sources has not been worked.
- **Input summing resistor matching.** This is where 1V/oct accuracy is spent once
  there are three inputs. Doepfer specs 0.1% for the same reason. Not yet specified here.
- ~~**Panel layout.**~~ **Resolved twice.** Layout and hole table are in the README's
  Panel section; both outputs come from [`../tools/gen_panel.py`](../tools/gen_panel.py).

  *First attempt — inherited holes.* The v2.2 panel is already 8 rows x 2 columns = 16
  positions, so v3 reused every hole *position* from
  `Gerber_precision-adder-new-better-panel` and only reassigned diameters between 6 mm
  jack and 5 mm toggle (8 of 18 changed). Two things fell out of drawing it. The
  silkscreen is the binding constraint, not the holes: a 6 mm jack in a 10.6 mm column
  pitch leaves 0.7 mm to the panel edge, so nothing can be labelled outboard of either
  column and every mark has to live in the centre channel or the vertical gaps. And the
  grouping was forced — three summed inputs sit together, so some rows carry two toggles,
  so a stage's `OUT` could not share its row. Outputs landed in pairs, row 5 serving the
  two switch rows above it and row 8 the two above it. Legible, but the panel could not
  say which output belonged to which stage.

  *Second — grouped, on new holes.* One box per stage: polarity switch, selector switch,
  that stage's own output. Six evenly spaced rows below the inputs, which the inherited
  pitches (12.4 / 15.9 / 16.2 / 12.4 mm) could not give, so the positions were refitted.
  The v3 main board is new anyway, and the style guide's inherit rule covers this case —
  positions are fitted once when the board is laid out, and inherited from then on. These
  are now that datum.

  What the grouping cost: a three-position selector needs a mark at its centre detent,
  and the only clear width at that height is the ~1.2 mm strip between the toggle nut and
  the box edge. One character fits there, two do not. So the detent carries the stage's
  odd interval — the 4th, or the 5th on stage 4 — and the two throws carry `MAJ` and
  `MIN`. It reads well, since the thirds are the pair you reach for, but it was a
  constraint before it was a preference. That mark is set at 1.0 mm against a house
  minimum of 1.6, and is the panel's one deliberate exception.

  Marks straddling the box edge were tried first and rejected: the two columns' detent
  marks ended up 1.6 mm apart across the centre line, where `4` and `5` read as the
  number 45 and neither belonged to a group. Inside its own box, each is unambiguous.

  The divider above the stages came out — four boxed groups already separate themselves
  from the input block, and the rule was doing the job twice.

  **`SUM`'s ring runs off the edge margin, closed anyway.** It is an output, so it takes
  the ring, but a ring is only visible if it clears the 8 mm nut, and a 20 mm panel
  carrying two 8 mm nuts has 4 mm of slack in total. At r 4.4 it ends up 0.07 mm from the
  cut on the outboard side — on the board, but well inside the 0.6 mm margin, and a fab
  may trim it. Two alternatives were drawn and dropped: a ~310° arc with the gap at the
  outboard side, which reads as a broken mark rather than a ring, and moving the columns
  inboard to make room, which shrinks the detent strip below what one character needs.
  The clipped circle is the least-bad of the three. It is recorded as a named exception
  in the generator's clearance report rather than by loosening `EDGE_MARGIN`, so it stays
  visible. `OUT1`-`OUT4` get no ring at all: each is inside a named box, and a second
  closed circle would cost `SUM`'s ring its meaning.

  The cascade arrows run across the top pair, down into the bottom-left group, and across
  the bottom pair. The middle leg is a dogleg rather than a diagonal — 4 mm of band
  against 10.8 mm of column pitch is a 15° line, and house routing is 0/90/45.

  **The polarity centre is marked `0`,** added after the panel was otherwise settled. The
  centre was originally left blank on the grounds that an unmarked detent reads as "off".
  It does not: a selector displays a value at all times, so a stage whose selector rests on
  the 4th reads as adding a fourth even with its polarity centred. The author misread his
  own panel that way, which is about as clear a test result as this kind of question gets.
  One rule now covers both toggles in a group — a three-position toggle's centre value goes
  in the strip between its nut and the box edge — and `OCT`'s two-position magnitude switch
  correctly has none.

  **Still to check:** the two toggles in a group are 13.0 mm apart, leaving 5.5 mm
  between nuts — better than the 4.9 mm of the row-based draft, still unproven here since
  v2.2 stacks no toggles. 1:1 print and a finger test before any fab order. And no DRC
  has been run: KiCad is not installed on the machine that generated the board.
- **`ON-ON-ON` variant.** Type 1 vs Type 2 differ in which pole combinations the
  three positions produce. Not yet pinned down for the quality switches.

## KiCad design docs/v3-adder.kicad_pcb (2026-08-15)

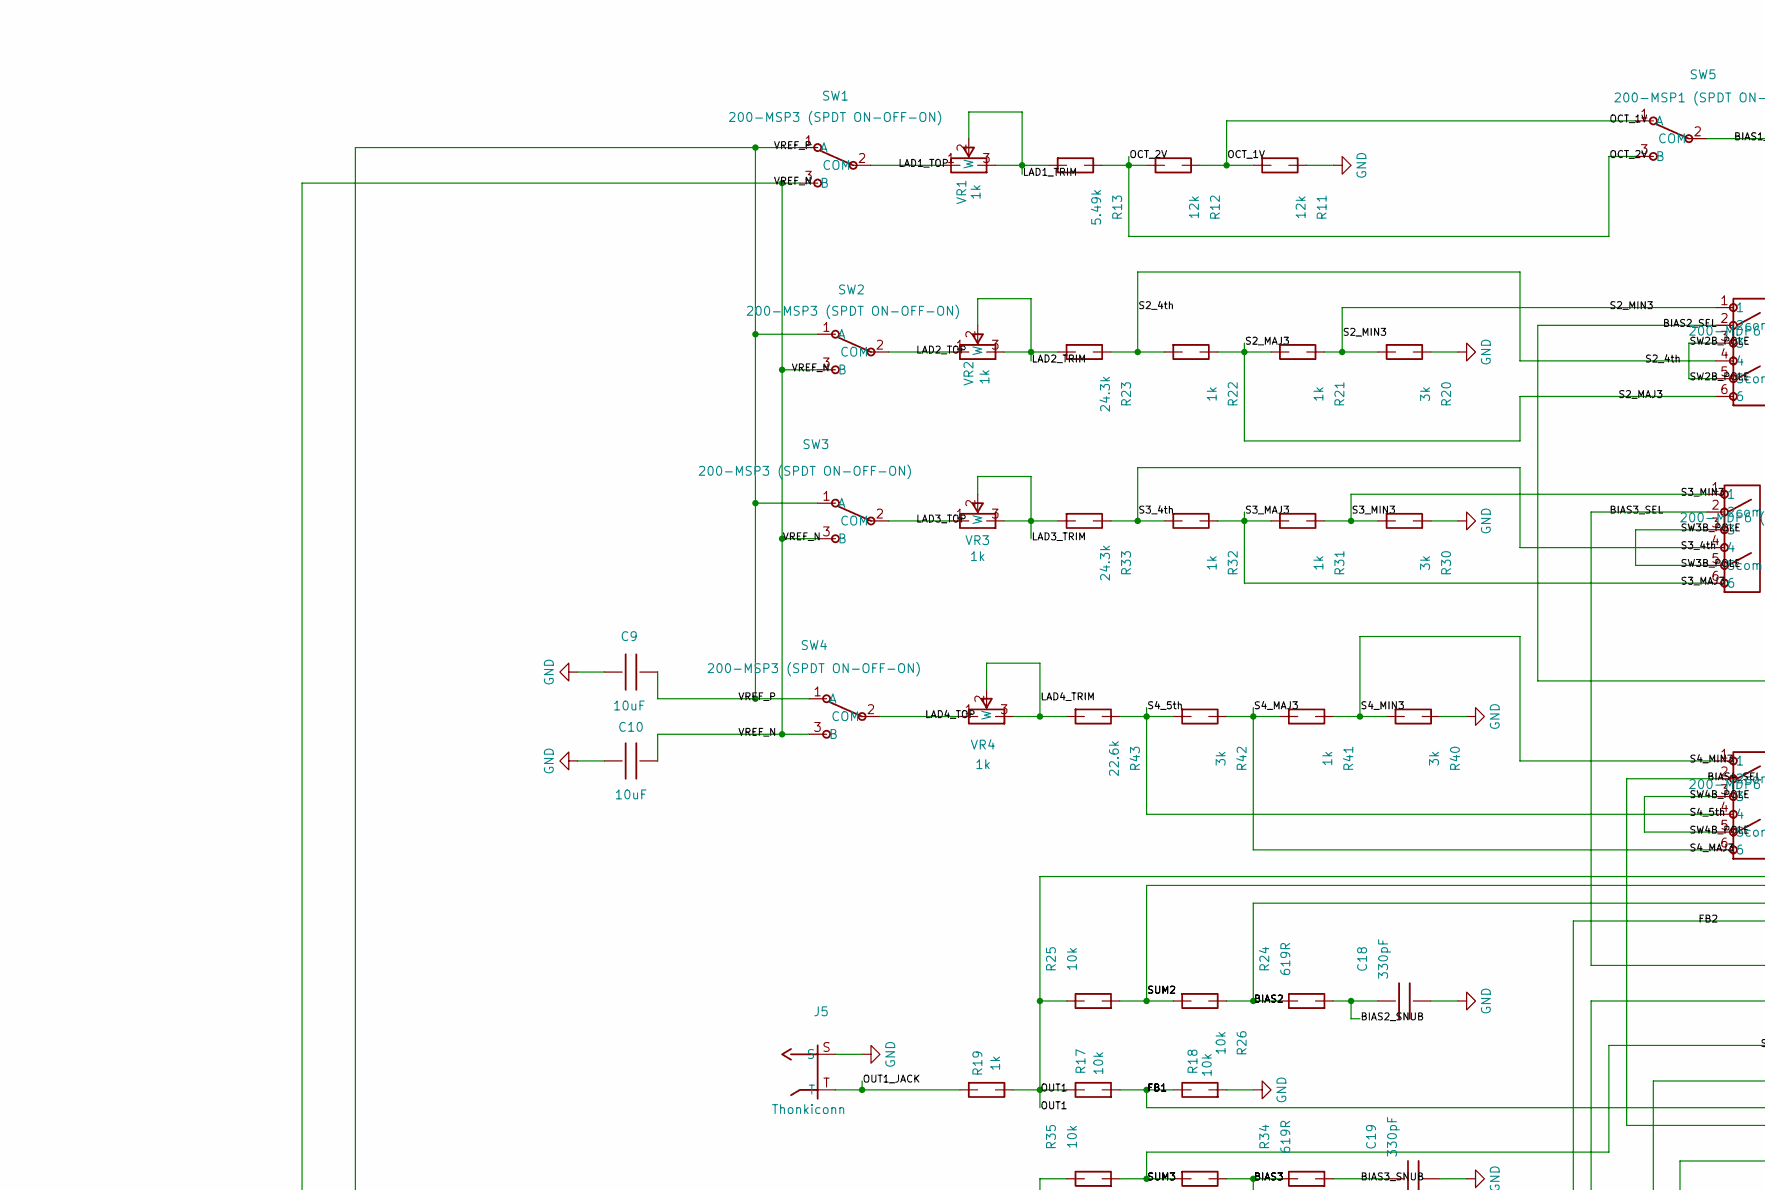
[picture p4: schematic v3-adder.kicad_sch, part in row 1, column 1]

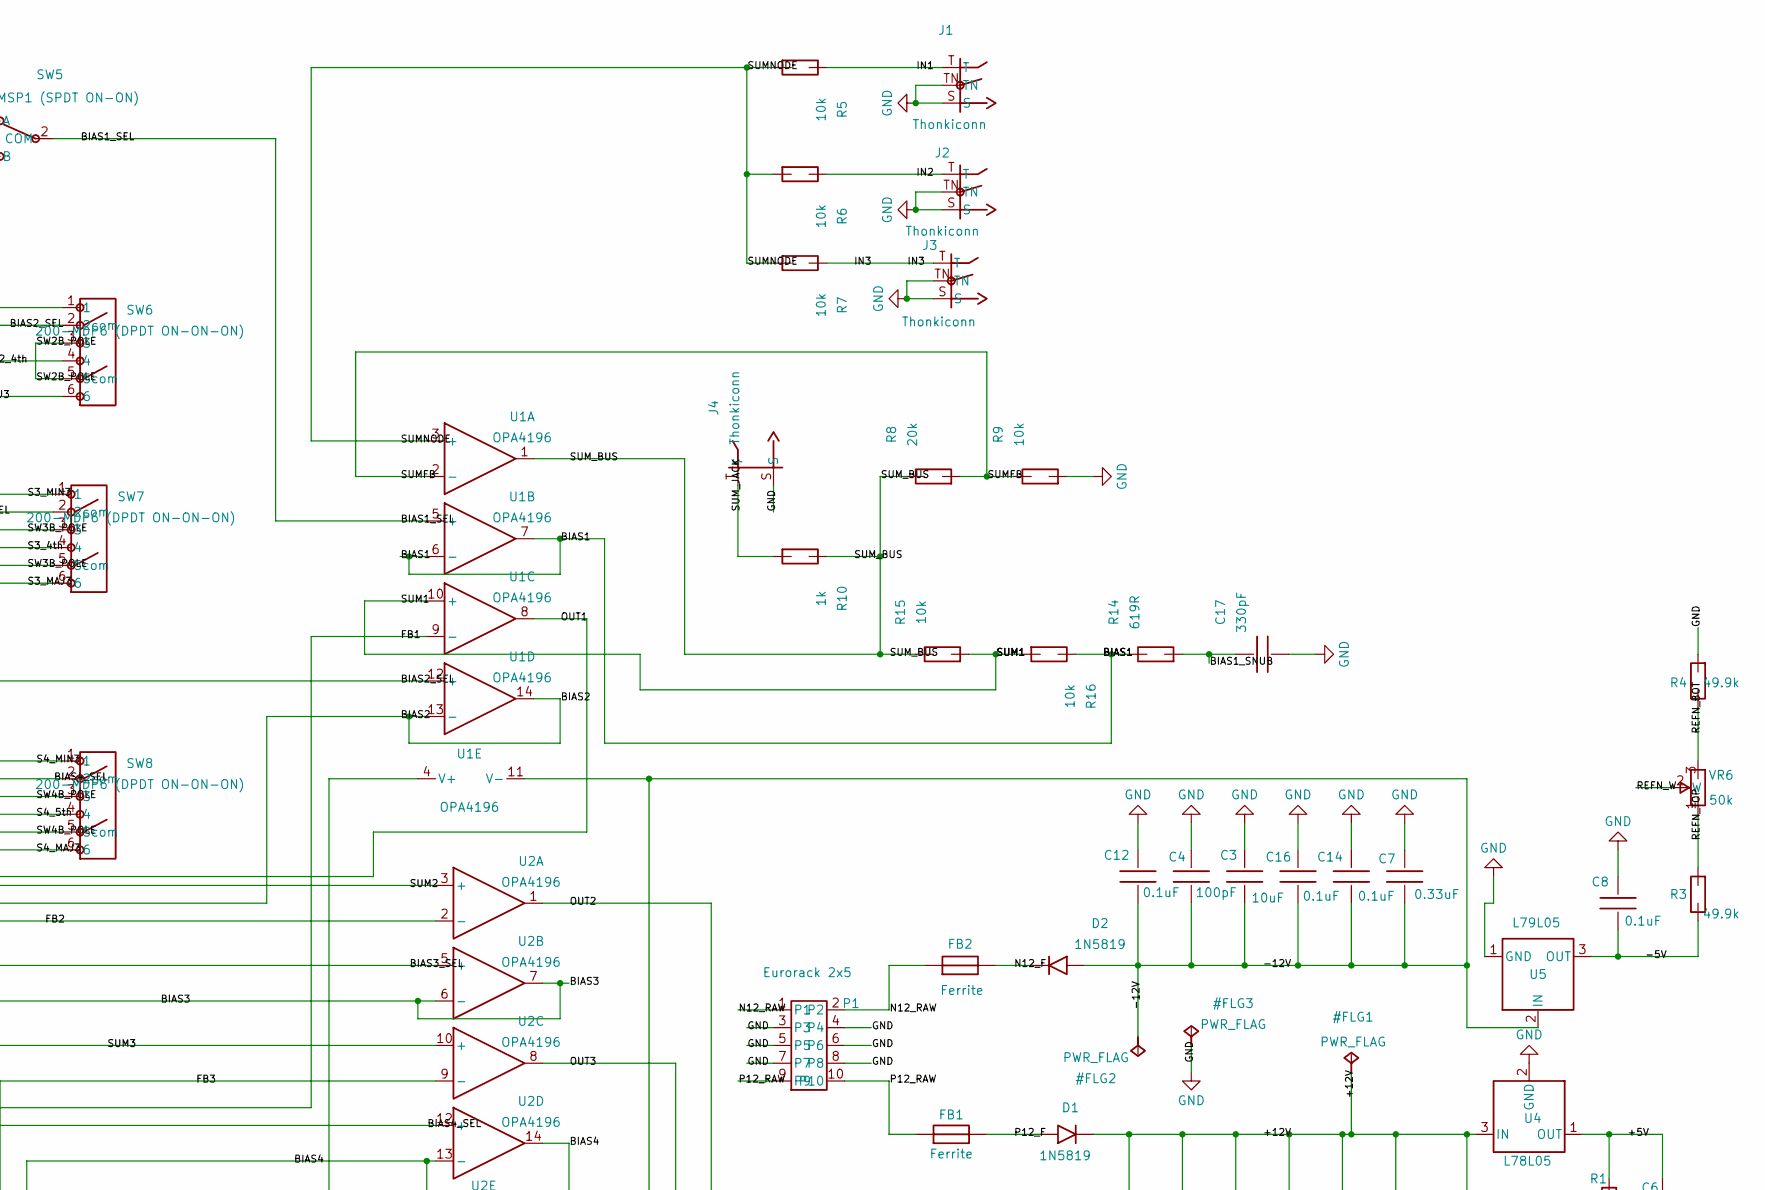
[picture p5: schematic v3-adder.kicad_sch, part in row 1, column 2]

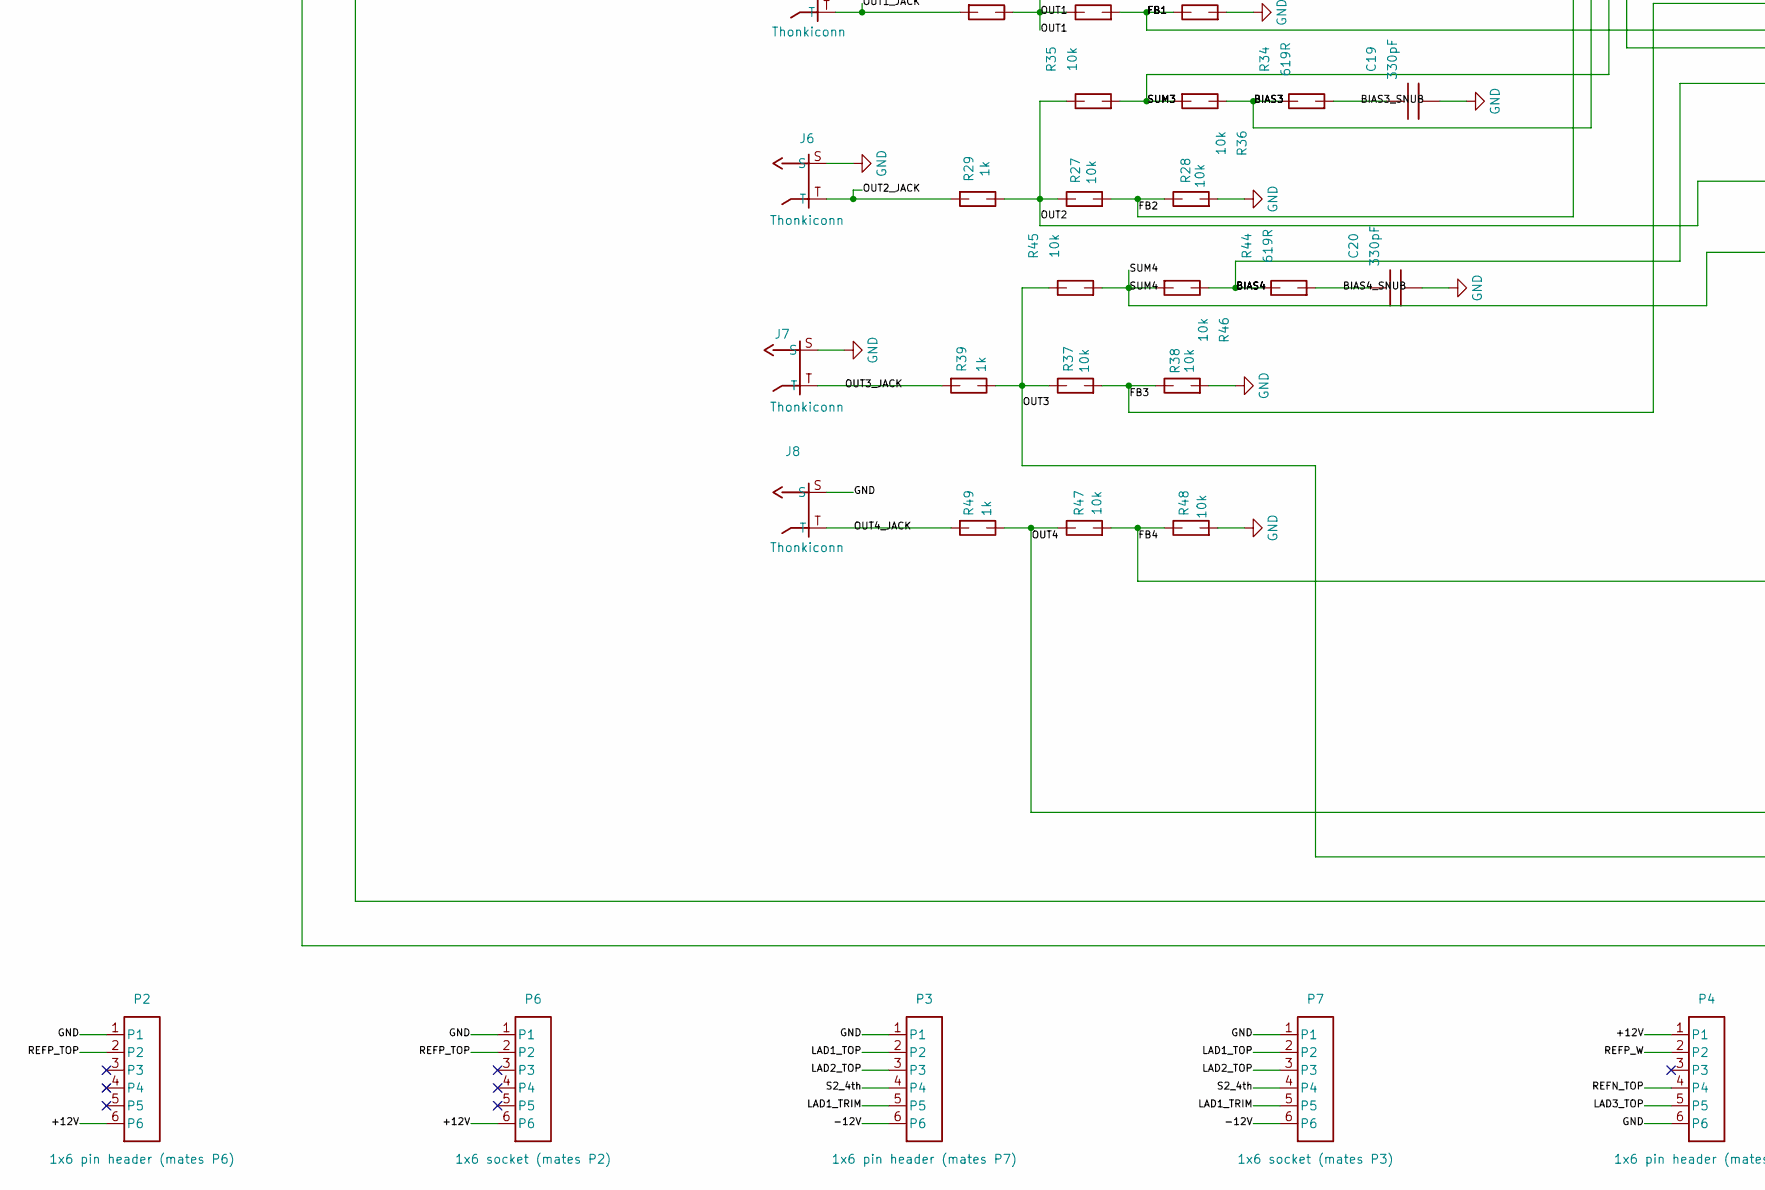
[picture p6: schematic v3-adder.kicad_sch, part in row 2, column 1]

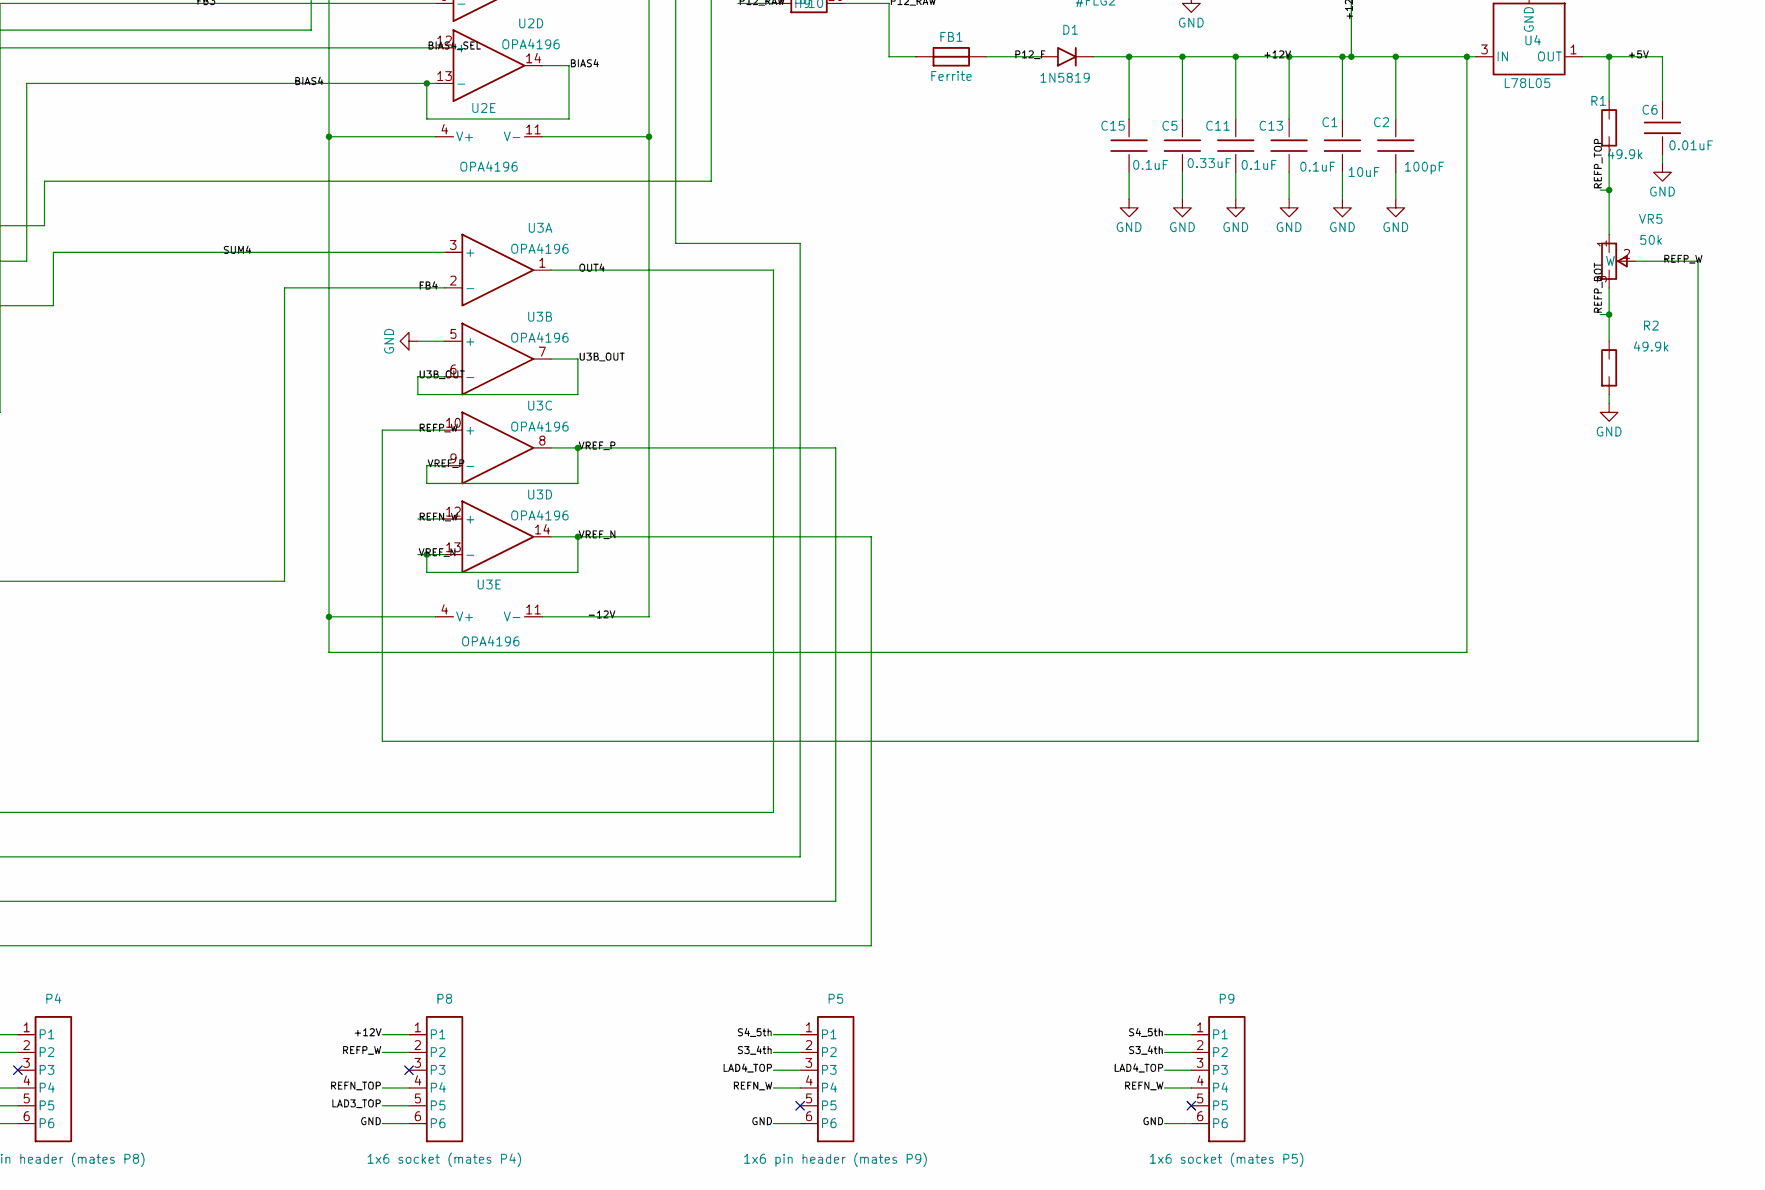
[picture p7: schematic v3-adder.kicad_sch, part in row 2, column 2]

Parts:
C1, C3, C9, C10: 10uF; CP_Radial_D5.0mm_P2.00mm
C2, C4: 100pF; C_1206_3216Metric
C5, C7: 0.33uF; C_1206_3216Metric
C6: 0.01uF; C_1206_3216Metric
C8, C11, C12, C13, C14, C15, C16: 0.1uF; C_1206_3216Metric
C17, C18, C19, C20: 330pF; C_1206_3216Metric
D1, D2: 1N5819; D_DO-41_SOD81_P10.16mm_Horizontal
FB1, FB2: Ferrite; R_Axial_DIN0207_L6.3mm_D2.5mm_P7.62mm_Horizontal
J1, J2, J3, J4, J5, J6, J7, J8: Thonkiconn; Thonkiconn_PJ301M
P1: Eurorack 2x5; IDC-Header_2x05_P2.54mm_Vertical
P2: 1x6 pin header (mates P6); PinHeader_1x06_P2.54mm_Vertical
P3: 1x6 pin header (mates P7); PinHeader_1x06_P2.54mm_Vertical
P4: 1x6 pin header (mates P8); PinHeader_1x06_P2.54mm_Vertical
P5: 1x6 pin header (mates P9); PinHeader_1x06_P2.54mm_Vertical
P6: 1x6 socket (mates P2); PinSocket_1x06_P2.54mm_Vertical
P7: 1x6 socket (mates P3); PinSocket_1x06_P2.54mm_Vertical
P8: 1x6 socket (mates P4); PinSocket_1x06_P2.54mm_Vertical
P9: 1x6 socket (mates P5); PinSocket_1x06_P2.54mm_Vertical
R1, R2, R3, R4: 49.9k; R_1206_3216Metric
R5, R6, R7, R9, R15, R16, R17, R18, R25, R26, R27, R28, R35, R36, R37, R38, R45, R46, R47, R48: 10k; R_1206_3216Metric
R8: 20k; R_1206_3216Metric
R10, R19, R21, R22, R29, R31, R32, R39, R41, R49: 1k; R_1206_3216Metric
R11, R12: 12k; R_1206_3216Metric
R13: 5.49k; R_1206_3216Metric
R14, R24, R34, R44: 619R; R_1206_3216Metric
R20, R30, R40, R42: 3k; R_1206_3216Metric
R23, R33: 24.3k; R_1206_3216Metric
R43: 22.6k; R_1206_3216Metric
SW1, SW2, SW3, SW4: 200-MSP3 (SPDT ON-OFF-ON); SW_Taiway_200_SPDT
SW5: 200-MSP1 (SPDT ON-ON); SW_Taiway_200_SPDT
SW6, SW7, SW8: 200-MDP6 (DPDT ON-ON-ON); SW_Taiway_200_DPDT
U1, U2, U3: OPA4196; SOIC-14_3.9x8.7mm_P1.27mm
U4: L78L05; TO-92_Inline
U5: L79L05; TO-92_Inline
VR1, VR2, VR3, VR4: 1k; Potentiometer_Bourns_3296W_Vertical
VR5, VR6: 50k; Potentiometer_Bourns_3296W_Vertical

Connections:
/+5V: C6.1, R1.1, U4.1 (OUT)
/+12V: C1.1, C2.1, C5.1, C11.1, C13.1, C15.1, D1.1 (K), P2.6, P4.1, P6.6, P8.1, U1.4 (V+), U2.4 (V+), U3.4 (V+), U4.3 (IN)
/-5V: C8.1, R3.1, U5.3 (OUT)
/-12V: C3.1, C4.1, C7.1, C12.1, C14.1, C16.1, D2.2 (A), P3.6, P7.6, U1.11 (V-), U2.11 (V-), U3.11 (V-), U5.2 (IN)
/BIAS1: R14.1, R16.1, U1.6 (-), U1.7
/BIAS1_SEL: SW5.2 (COM), U1.5 (+)
/BIAS1_SNUB: C17.1, R14.2
/BIAS2: R24.1, R26.1, U1.13 (-), U1.14
/BIAS2_SEL: SW6.2 (2com), U1.12 (+)
/BIAS2_SNUB: C18.1, R24.2
/BIAS3: R34.1, R36.1, U2.6 (-), U2.7
/BIAS3_SEL: SW7.2 (2com), U2.5 (+)
/BIAS3_SNUB: C19.1, R34.2
/BIAS4: R44.1, R46.1, U2.13 (-), U2.14
/BIAS4_SEL: SW8.2 (2com), U2.12 (+)
/BIAS4_SNUB: C20.1, R44.2
/FB1: R17.2, R18.1, U1.9 (-)
/FB2: R27.2, R28.1, U2.2 (-)
/FB3: R37.2, R38.1, U2.9 (-)
/FB4: R47.2, R48.1, U3.2 (-)
/IN1: J1.T, R5.1
/IN2: J2.T, R6.1
/IN3: J3.T, R7.1
/LAD1_TOP: P3.2, P7.2, SW1.2 (COM), VR1.1
/LAD1_TRIM: P3.5, P7.5, R13.2, VR1.2 (W_2), VR1.3
/LAD2_TOP: P3.3, P7.3, SW2.2 (COM), VR2.1
/LAD2_TRIM: R23.2, VR2.2 (W_2), VR2.3
/LAD3_TOP: P4.5, P8.5, SW3.2 (COM), VR3.1
/LAD3_TRIM: R33.2, VR3.2 (W_2), VR3.3
/LAD4_TOP: P5.3, P9.3, SW4.2 (COM), VR4.1
/LAD4_TRIM: R43.2, VR4.2 (W_2), VR4.3
/N12_F: D2.1 (K), FB2.2
/N12_RAW: FB2.1, P1.1, P1.2
/OCT_1V: R11.2, R12.1, SW5.1 (A)
/OCT_2V: R12.2, R13.1, SW5.3 (B)
/OUT1: R17.1, R19.1, R25.1, U1.8
/OUT1_JACK: J5.T, R19.2
/OUT2: R27.1, R29.1, R35.1, U2.1
/OUT2_JACK: J6.T, R29.2
/OUT3: R37.1, R39.1, R45.1, U2.8
/OUT3_JACK: J7.T, R39.2
/OUT4: R47.1, R49.1, U3.1
/OUT4_JACK: J8.T, R49.2
/P12_F: D1.2 (A), FB1.2
/P12_RAW: FB1.1, P1.9, P1.10
/REFN_BOT: R4.1, VR6.3
/REFN_TOP: P4.4, P8.4, R3.2, VR6.1
/REFN_W: P5.4, P9.4, U3.12 (+), VR6.2 (W_2)
/REFP_BOT: R2.1, VR5.3
/REFP_TOP: P2.2, P6.2, R1.2, VR5.1
/REFP_W: P4.2, P8.2, U3.10 (+), VR5.2 (W_2)
/S2_4th: P3.4, P7.4, R22.2, R23.1, SW6.4
/S2_MAJ3: R21.2, R22.1, SW6.6
/S2_MIN3: R20.2, R21.1, SW6.1
/S3_4th: P5.2, P9.2, R32.2, R33.1, SW7.4
/S3_MAJ3: R31.2, R32.1, SW7.6
/S3_MIN3: R30.2, R31.1, SW7.1
/S4_5th: P5.1, P9.1, R42.2, R43.1, SW8.4
/S4_MAJ3: R41.2, R42.1, SW8.6
/S4_MIN3: R40.2, R41.1, SW8.1
/SUM1: R15.2, R16.2, U1.10 (+)
/SUM2: R25.2, R26.2, U2.3 (+)
/SUM3: R35.2, R36.2, U2.10 (+)
/SUM4: R45.2, R46.2, U3.3 (+)
/SUMFB: R8.2, R9.1, U1.2 (-)
/SUMNODE: R5.2, R6.2, R7.2, U1.3 (+)
/SUM_BUS: R8.1, R10.1, R15.1, U1.1
/SUM_JACK: J4.T, R10.2
/SW2B_POLE: SW6.3, SW6.5 (5com)
/SW3B_POLE: SW7.3, SW7.5 (5com)
/SW4B_POLE: SW8.3, SW8.5 (5com)
/U3B_OUT: U3.6 (-), U3.7
/VREF_N: C10.1, SW1.3 (B), SW2.3 (B), SW3.3 (B), SW4.3 (B), U3.13 (-), U3.14
/VREF_P: C9.1, SW1.1 (A), SW2.1 (A), SW3.1 (A), SW4.1 (A), U3.8, U3.9 (-)
GND: C1.2, C2.2, C3.2, C4.2, C5.2, C6.2, C7.2, C8.2, C9.2, C10.2, C11.2, C12.2, C13.2, C14.2, C15.2, C16.2, C17.2, C18.2, C19.2, C20.2, J1.S, J1.TN, J2.S, J2.TN, J3.S, J3.TN, J4.S, J5.S, J6.S, J7.S, J8.S, P1.3, P1.4, P1.5, P1.6, P1.7, P1.8, P2.1, P3.1, P4.6, P5.6, P6.1, P7.1, P8.6, P9.6, R2.2, R4.2, R9.2, R11.1, R18.2, R20.1, R28.2, R30.1, R38.2, R40.1, R48.2, U3.5 (+), U4.2 (GND), U5.1 (GND)

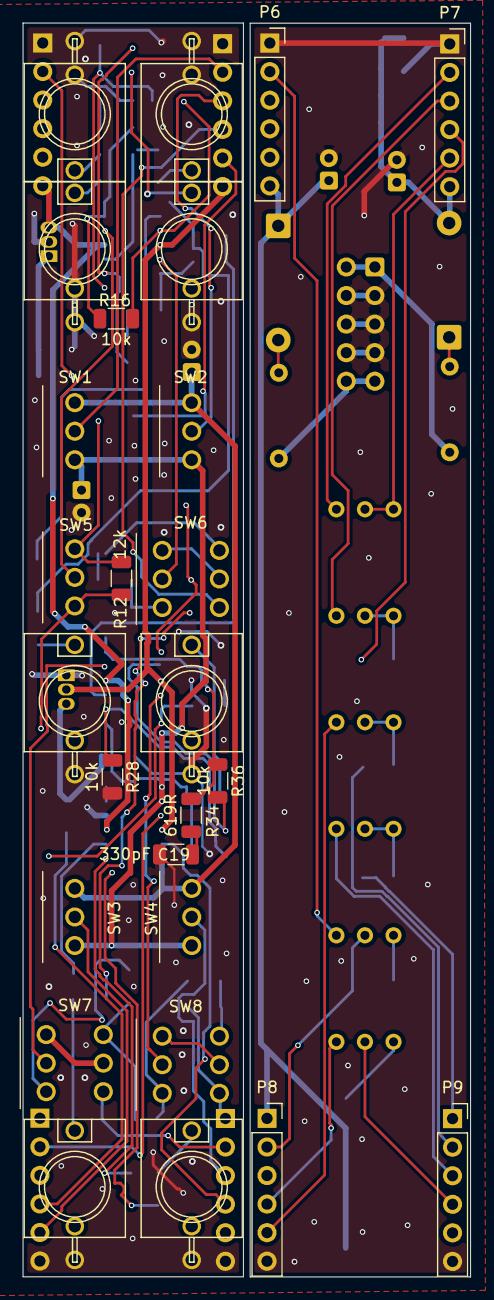
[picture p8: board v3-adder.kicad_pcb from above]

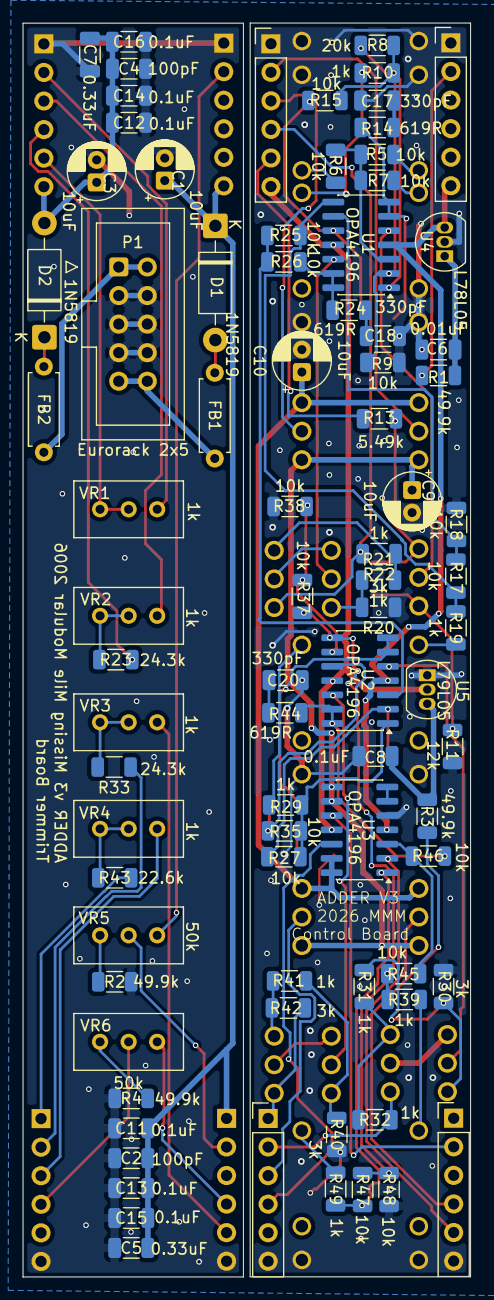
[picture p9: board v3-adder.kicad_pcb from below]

Board: 2 copper layers, 39.8 x 111.5 mm, 109 parts (83 on the bottom side), 75 nets.

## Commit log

2026-08-05 Document v3 chord-generator proposal and interval study
    Expand the README with what v2.2 can actually produce (39 distinct
    voltages, suspended-pentatonic pitch classes), the v3 proposal that
    fixes the redundant fifth+fourth pair, a comparison against the
    Doepfer A-185-2, and an appendix of interval-set search results.
    Add interval-study.py, which reproduces every chart in the appendix,
    and docs/DESIGN-LOG.md, which records the options considered and
    rejected. Ignore the raw session transcript.
2026-08-05 Untrack machine-local Claude Code settings
    .claude/settings.local.json is per-machine config — absolute WSL paths
    and a permission allowlist — not something to share. Remove it from
    tracking and ignore it; the file stays in place locally.
2026-08-05 Draw the v3 panel, reusing v2.2's hole positions
    Closes open question 3 in the design log: the v3 arrangement had been
    confirmed as a count of 16 positions but never drawn.
    The built v2.2 panel is already 8 rows x 2 columns = 16 positions, which
    is exactly what v3 needs, so the outline, the mounting holes and every
    hole position carry over untouched. Only the diameter at each position is
    reassigned between the 6 mm jack and the 5 mm toggle - 8 of 18 holes
    change size, 10 do not. Geometry diffed against Gerber_Drill_NPTH.DRL and
    Gerber_Drill_PTH.DRL; max drift 0.001 mm, which is EasyEDA's own rounding
    (it writes the same row as both 84.749 and 84.750).
    Layout follows two rules: the left col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
2026-08-08 Panel style v1.01 — de-brand it into a house style
    The guide is a house style for my panels, not a Kassutronics document, and the
    next panels will not all be Kassutronics ports. So:
    - retitled, and reframed as a drawing spec rather than a description of one
    generator. Rules that were stated as tool behaviour are stated as the rule
    being enforced; a hand-drawn SVG like docs/v3-panel.svg can satisfy it.
    - the wordmark now names who designed the module: MISSING MILE MODULAR (MMM)
    for originals, the original maker's name for a port or revision, and 508 on
    this adder, which is what the built v2.2 panel carries.
    - the inherited-hole rule covers both cases — a panel serving an existing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
2026-08-08 Panel: put every jack name below its jack
    Input names sat below their jacks and output names above theirs, which is not a
    rule anyone can read off the panel. All eight now sit below, at nut bottom +
    2.15 mm.
    Below an output row that leaves 4.65 mm before the next toggle's nut, which will
    not hold a jack name, a stage name and a polarity mark. The stage name moves: it
    now shares the baseline of its row's "+" mark, 4.20 mm above the row, where
    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
2026-08-08 Panel: generated KiCad board, one box per stage
    Replaces the hand-drawn SVG with tools/gen_panel.py, which emits both
    docs/v3-panel.kicad_pcb and docs/v3-panel.svg from one layout table so the two
    cannot disagree, and refuses to write if anything overlaps.
    The layout changes shape. Inputs and SUM stay at the top; below the divider are
    four boxed groups, one per stage - polarity switch, selector switch, that
    stage's own output. The row-based draft could not do that: three summed inputs
    have to sit together, so some rows carried two toggles, so outputs landed in
    shared pairs and the panel could not say which output belonged to which stage.
    Hole positions are therefore refitted rather than in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
    [v3-panel.kicad_pcb]
2026-08-08 Panel: ring SUM, drop the divider, draw the cascade arrows
    - SUM is an output, so it takes the ring. It cannot close: a ring is only
    visible if it clears the 8 mm nut, and a 20 mm panel carrying two of them has
    4 mm of slack all told. At r 4.4 it reaches EDGE_MARGIN on the outboard side,
    so it is drawn as a ~310 degree arc with the gap there. Moving the columns in
    to fit a full circle would shrink the detent strip below one character.
    Its label baseline is measured from the ring, and IN3 follows it so the row
    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
    [v3-panel.kicad_pcb]
2026-08-08 Panel: close SUM's ring, swap OCT's 1 and 2
    The ring is a full circle now. It sits 0.07 mm from the cut on the outboard
    side - on the board, but well inside the 0.6 mm edge margin, so expect a fab to
    trim its outer edge. Taken deliberately: a broken ring reads worse than a
    clipped one. Recorded as a named exception in the clearance report rather than
    by loosening EDGE_MARGIN, so it stays visible rather than becoming a habit.
    OCT's magnitude switch now reads 1 up, 2 down.
    The edge check only ever looked at straight silk lines, which is how a ring
    reaching the cut could have gone unnoticed - it now covers arcs and circles
    too, and text against the ring is checked separately since SUM's label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
    [v3-panel.kicad_pcb]
2026-08-08 Study: what stage 3 should be, and what the pass-throughs buy
    Chart 9 in interval-study.py, so the numbers behind the stage-set question are
    reproducible like the rest.
    Stage 3 as a pure 4th costs every triad - a stage that cannot make a third
    breaks the stack, and tetrads fall 79 to 42. Trading one third for the 5th
    (candidates B and C) buys 2 semitones of chromatic range and costs one triad
    type and a chunk of the voicings. Candidate A, what is drawn now, is the only
    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
2026-08-08 Panel: mark the polarity centre 0
    The centre was left blank on the grounds that an unmarked detent reads as
    "off". It does not. A selector shows a value at all times, so a stage whose
    selector rests on its 4th reads as adding a fourth even when its polarity is
    centred and the stage contributes nothing.
    One rule now covers both toggles in a group: a three-position toggle's centre
    value is marked in the strip between its nut and the box edge. The selector
    detent placement was refactored to share it. OCT's magnitude switch is
    two-position and correctly gets no mark.
    Clearances unchanged - the new marks sit in the same strip as the detent
    values, worst case still 0.25 mm.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
    [v3-panel.kicad_pcb]
2026-08-08 Transcribe the v2.2 circuit, and sketch what v3 changes
    The schematic PDF is an EasyEDA vector export with no netlist in it, so nothing
    converts it to KiCad - a PDF holds line segments that happen to touch, not
    connectivity. Redrawing is the only route, and reading the connectivity off the
    drawing is the slow part of that, so it is written down here once.
    The design: a trimmed +/-2.5 V reference pair is the only precision source.
    Each stage picks a polarity with its SPDT, scales it to that stage's interval
    with a divider, buffers it, and sums it with the stage input through two 10k
    into a non-inverting amp of gain 2 - the gain undoing the divide-by-two, so
    OUT = IN + Vbias exactly. The swit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
2026-08-08 Generate the v3 schematic as a KiCad .kicad_sch
    tools/gen_schematic.py emits docs/v3-adder.kicad_sch from a netlist table:
    102 parts, 72 nets, 12 op-amp channels over three OPA4196 with one spare tied
    off as a follower. Topology per docs/v2.2-topology.md - the reference block,
    the power block and the summing topology are v2.2's, unchanged.
    A scaffold, not a finished drawing. Placement is a grid and connectivity is by
    net label on a pin stub rather than routed wire, which cannot be got subtly
    wrong the way routing can and survives rearranging the symbols afterwards.
    Two bugs the first netlist dump caught, both invisible to a connectivity check
    because every net still had two or more pins: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
    [v3-adder.kicad_sch, v3-panel.kicad_pcb]
2026-08-08 Schematic: fix unresolved symbols, draw real bodies
    Every symbol rendered as a box with "??" - KiCad's missing-symbol placeholder.
    lib_symbols entries must be named with the full LIBRARY:NAME, and they were
    named bare ("R" where instances referenced "adder:R"), so nothing resolved.
    The check that should have caught this could not: it compared
    libId.split(':')[-1] on both sides, stripping the very prefix that was wrong.
    It now compares whole lib_id strings, and additionally confirms each
    instantiated unit has a matching body, and that all 267 pin coordinates read
    back out of the written file land on a wire endpoint - so the label stubs are
    attached to pins rather than merely near them.
    Bodi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
    [v3-adder.kicad_sch]
2026-08-08 Schematic: ERC-clean, and run KiCad's own checks
    KiCad 7 and 10 are installed on this machine; kicad-cli runs from WSL against
    the Windows binary, so ERC and DRC are no longer things I could only promise to
    someone else. tools/kicad-check.sh runs both and plots both.
    ERC went 553 violations to 23, and 3 errors to 0. What it caught:
    - BIAS and SUM were SHORTED on every stage. Two 10k resistors sat 12 mm apart
    but each occupies +/-7.62 mm with its label stubs, so the stubs overlapped
    and tied the bias buffer straight past its summing resistor. My checks could
    not see it: I verify the netlist I declare, KiCad computes connectivity from
    geometry. Parts are now placed one per cell on a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
    [v3-adder.kicad_sch, v3-panel.kicad_pcb]
2026-08-08 Deterministic ids; untrack KiCad's per-user project state
    Both generators minted fresh uuid4s on every run, so regenerating an unchanged
    design rewrote every line and git diff could not show what actually changed.
    Ids are now uuid5 from a fixed namespace and a counter.
    docs/v3-adder.kicad_prl is KiCad's per-user local state, written when the CLI
    touched the project. Untracked and ignored, as .kicad_prl generally should be.
    [v3-adder.kicad_sch, v3-panel.kicad_pcb]
2026-08-08 Schematic: fix three functional defects found reviewing it
    Asked to verify the schematic does what v3 needs before layout. The structure
    was right - three summed inputs to SUM, four cascaded stages of polarity switch
    plus tap selector plus buffer plus gain-2 adder, no leftover v2.2 passthru
    buffers - but three things were wrong.
    1. Unpatched inputs did not sum to zero. Each input jack had a 100k pulldown,
    which puts 110k rather than a driven 0 V on that leg of the passive
    averager. With one input patched - the normal case - the summer's gain was
    2.538 instead of 1.0, so a 1V/oct signal came out transposed by over an
    octave and a half. Fixed by wiring the Thonkiconn's own switch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
    [v3-adder.kicad_sch]
2026-08-08 Schematic: wire the real Taiway switches, cross-check against the panel
    Part is Taiway 200-MDP6-T1B1M2QE. Datasheet fetched and read: series 200
    subminiature, pins 1-2-3 pole A with 2 common, 4-5-6 pole B with 5 common,
    B1 bushing 10-48 UNS Ø4.80 with a recommended Ø4.95 panel hole - so the panel's
    Ø5.0 holes are right, though it does not cut the optional 4.55 anti-rotation
    flat.
    The selector was drawn as an ideal 4-pin 1P3T, which no such part is. It is now
    a real 6-pin DPDT with the poles cascaded: pole A's common is the output, one
    of its throws is a tap outright, the other feeds pole B's common, and pole B
    picks between the remaining two. Tying the commons instead would short two
    lad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
    [v3-adder.kicad_sch]
2026-08-08 Simulate the ON-ON-ON selector from Taiway's contact table
    The MDP-6 sequence, supplied from the datasheet:
    position 1 2-3, 5-6
    position 2 2-3, 5-4
    position 3 2-1, 5-4
    which is the variant the generator already assumed, so no wiring changed. A
    correction to what I said last commit: MDP-6 is not on the ordering page or the
    termination pages I read, but it is documented - I generalised from the pages I
    had rather than from the whole sheet.
    check_selector() now walks each selector through all three positions from that
    table and asserts the output reaches the intended tap, and exactly one tap.
    That last part is the point: the cascaded-pole wiring is not obviously co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
2026-08-08 Switch orientation does not matter, and now the checks say so
    Fitting the ON-ON-ON 180 degrees round swaps diagonally opposite pads
    (6<->1, 5<->2, 4<->3) and reverses the lever. Those two cancel: read against
    the board's own pad numbers from lever-up to lever-down, the contact sequence
    is identical. So a reversed part has wrong pin numbers and right behaviour,
    and the footprint and panel need not care which way it goes in. True of both
    ON-ON-ON variants, since it follows from the body being symmetric.
    That retires the bench check I flagged last commit as still outstanding - it
    was not a real open item. check_rotation_symmetry() asserts it against the
    contact table so the claim survives the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
2026-08-08 Fix both regulator pinouts; wire them by function, not pin number
    Asked whether U5 pin 3 is -5V. It is, and that one happens to be right - but
    checking it against the v2.2 schematic showed the other five regulator pins
    were wrong.
    The 78L05 and 79L05 do not share a pinout in TO-92:
    78L05 3 = IN 2 = GND 1 = OUT
    79L05 2 = IN 1 = GND 3 = OUT
    I had one generic REG symbol numbered 1=IN, 2=GND, 3=OUT and used it for both,
    so U4 had +12V on its output pin and +5V on its input, and U5 had -12V on its
    ground pin and ground on its input. Only U5 pin 3 landed correctly, which is
    the pin that got asked about.
    Now two symbols carrying the real numbering, and add_reg() looks the number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
    [v3-adder.kicad_sch]
2026-08-09 v3-final
    sch complete, panel complete
    [v3-adder.kicad_sch]
2026-08-09 component refinement
    [v3-adder.kicad_sch, v3-panel.kicad_pcb]
2026-08-10 Update gitignore and remove cached files
    Add gitignore rules for Python bytecode and KiCad backup directories. Remove accidentally committed Python cache files from version control.
2026-08-10 Normalise line endings for KiCad files
    KiCad on Windows saves CRLF while the committed copies were LF, so merely
    opening and saving a schematic or board showed up as every line changed:
    3,878 lines on the panel and 4,932 on the symbol library, with zero content
    difference in either. That buries real edits and makes review impossible by
    inspection.
    .gitattributes pins the KiCad text formats, and the sources and docs, to LF.
    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
2026-08-10 Board: outline, and place every panel-defined part
    docs/v3-adder.kicad_pcb gets a 19.0 x 111.5 mm Edge.Cuts rectangle at (0.5,
    8.5) and the sixteen components whose positions the panel dictates - eight
    jacks and eight toggles - placed on the panel's own hole coordinates, so board
    and panel share one frame of reference.
    Rotations are not cosmetic. Switches sit at 90 so their throw axis runs
    vertically, matching the +/- above and below each toggle on the panel. J1 and
    J2 are at 180 because the input rows are 12.0 mm apart while the Thonkiconn
    footprint is 13.15 mm long: at 0 their pads overlap the row below by 1.15 mm.
    Flipped, the tails point away and the pair clears by 0.35 mm. That is the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
    [v3-adder.kicad_pcb]
2026-08-10 Untrack KiCad's project lock file
    ~v3-adder.kicad_pro.lck exists only while the project is open in KiCad, so it
    should never be committed. Removed and ignored.
2026-08-10 Narrow the column pitch to 10.4 so part bodies clear the board edge
    The DPDT selector is 9.10 mm wide once rotated for a vertical throw, so two of
    them occupy 18.2 mm of a 20 mm panel - 1.8 mm of slack for everything else. At
    the old 10.8 pitch their bodies, and the 9.00 mm jack bodies, overhung a 19 mm
    PCB by about 0.45 mm a side.
    The fix trades against panel legibility, because the detent mark sits between a
    toggle nut and its box edge, and moving a column inward closes that gap:
    pitch 10.8 marks 0.25 mm board must be 19.90 mm
    pitch 10.6 marks 0.20 mm board must be 19.70 mm
    pitch 10.4 marks 0.15 mm board must be 19.50 mm
    pitch 10.0 marks 0.05 mm - unmanufacturable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
    [v3-adder.kicad_pcb, v3-panel.kicad_pcb]
2026-08-14 Give the precision nets their own class, and stop sizing traces by current
    Nothing on this board is current-limited: three quad op-amps, two 100 mA
    regulators and four 30k ladders draw well under 15 mA a rail, and IPC-2221
    puts a 0.25 mm outer-layer trace at ~0.9 A. What actually constrains width
    is the SOIC-14 escape. Pads 0.6 mm wide on 1.27 mm pitch leave a 0.67 mm
    gap, so a track between two pins needs width + 2 x clearance <= 0.67 --
    0.27 mm at our 0.2 mm clearance. Default was 0.5 mm and could not fit at
    all. Drop it to 0.25 to match what was already being drawn by hand, and
    give the rails their own 0.5 mm class.
    HighZ collects the 21 patterns whose voltage is set by the 0.1% ladders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
2026-08-14 Put component values on silk, and write them the same way in both files
    Moves all 68 Fab-layer values to the matching silk layer, F.Fab -> F.SilkS
    and B.Fab -> B.SilkS so back-side parts keep their mirrored justify. The 20
    values that were already hidden stay hidden: "200-MDP6 (DPDT ON-ON-ON)" has
    nowhere to go on a 19.6 mm board.
    Trailing zeros that carry no information go with them -- 10.0k reads 10k,
    1.00k reads 1k -- while 49.9k, 24.3k, 22.6k, 5.49k and 619R keep every
    digit. Tolerance was never legible at 4 HP anyway; it lives in the BOM.
    This turned out to be a consistency fix rather than a cosmetic one. The
    schematic was the clean side: all ten 1k parts read 1.00k there and all
    twen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
    [v3-adder.kicad_pcb, v3-adder.kicad_sch]
2026-08-14 Panel: KiCad 10 re-save and its first gerber set
    Opening the panel in KiCad 10 upgraded the board from the 20221018 format
    gen_panel.py writes. Geometry is untouched -- 52 gr_line, 20 gr_arc, 17
    gr_circle and 85 gr_text before and after -- but re-running gen_panel.py
    will now produce a large reverse diff, so the generator and the file have
    parted ways.
    Gerbers plotted to docs/adder_panel_gerbers, matching how the v2.x fab
    output is kept in the repo.
    .gitignore picks up manual "save as" copies; an 820K "v3-adder - bak"
    sitting next to the real board is not history worth keeping.
    [v3-panel-B_Cu.gbr, v3-panel-B_Mask.gbr, v3-panel-B_Silkscreen.gbr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]
2026-08-14 gen_panel.py: emit KiCad 10's format so the panel stops drifting
    The script wrote format 20221018. Opening the panel in KiCad 10 upgraded it
    in place, rewrote 1939 lines, and left the generator unable to reproduce its
    own file -- any regen would have thrown away whatever KiCad normalised. This
    teaches it the 10.0 shape instead: tab-indented multi-line elements, uuid in
    place of tstamp, (fill no) rather than (fill none), a trailing
    (embedded_fonts no), and 10.0's layer numbering, which is not the old one --
    B.Cu moved 31 -> 2, F.SilkS 37 -> 5, Edge.Cuts 44 -> 25.
    The setup block is carried verbatim from a KiCad save. It is all plot
    boilerplate and none of it is ours, but emitting it keeps a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
    [v3-panel.kicad_pcb]
2026-08-14 Sockets on the trimmer board, and give every footprint a 3D model path
    The two cards' connectors were both on B.Cu, facing the same way, so they
    could never have mated. Board B -- the one carrying VR1-VR6 -- now takes
    PinSocket_1x06 on F.Cu, facing forward at board A's pins, which stay as
    headers on A's rear. The cards stack by a plain 20.2 mm translation, one
    board pitch, no flip.
    Placed at rotation 0 rather than 180. A board footprint stores pad
    coordinates with the rotation already baked in, while the library file
    stores them unrotated, so instantiating the library body at rot 180 put the
    pads in mirror order and broke every connection but pin 1. At rot 0 the
    library coordinates are used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
    [v3-adder.kicad_pcb]
2026-08-14 BOM: state the height limit the 3D models were already assuming
    The electrolytics were listed only as "10uF electrolytic" with a 5 mm-diameter
    footprint and nothing about height, while the 3D model is a low-profile 5 mm
    can. Nothing in the document said it had to be.
    It matters for exactly two of the four. The boards stack, and the only parts in
    the gap are those on the control board's rear -- which is where C9 and C10 are.
    C1 and C3 sit on the trimmer board's rear facing the back of the case, with
    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
2026-08-14 BOM: C9/C10 need ESR, and specify it before someone "upgrades" it
    Ran the OPA4196 numbers instead of guessing. The datasheet rates it to drive
    1 nF bare; C9 and C10 are 10 uF hanging off unity-gain reference buffers, ten
    thousand times that. The capacitor's ESR is what holds the loop together, so
    it is a specified parameter, not a defect.
    TI Table 3 (SBOS869) stops characterising at 1 uF, where it wants 3.6 ohm for
    45 degrees and 10 for 60. Extrapolating a decade puts 10 uF at roughly 0.8 and
    2.2 ohm. A MnO2 tantalum (0.5-3) or an ordinary aluminium electrolytic (1-3)
    lands in that window, which is presumably why v2.2 works. A ceramic at 2-10
    milliohm is ~200x short, and -- the part worth w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
2026-08-14 Put the board-to-board connectors in the schematic
    The eight interconnect footprints existed only on the board, carrying REF** and
    absent from the schematic entirely. Update PCB from Schematic would have offered
    to delete them, they were missing from the BOM, and nothing checked their pin
    mapping -- it was correct, but only because it had been checked by hand.
    Adds adder:HDR1x6 to the symbol library and eight instances: P2-P5 are the pin
    headers on the control board's rear, P6-P9 the sockets on the trimmer board's
    front, each Value naming the part it mates with. Board footprints annotated to
    match. The five spare pins per side are carried as no-connects so they stay
    available rather than be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
    [v3-adder.kicad_pcb, v3-adder.kicad_sch]
2026-08-14 Add the 3D models, vendor and exported
    eurorack.3dshapes now holds the three files the custom footprints were
    pointing at, so every model reference on the adder resolves -- 14 of 14, where
    it was 11 before. The inferred SPDT filename turned out to be right.
    Also carries three models this project does not use (100SPxT3B1M1xE, the Alpha
    RD901F pot, vactrolModel). The library is shared across modules by design, so
    they belong with it rather than beside whichever board needs them first.
    docs/boards.step and docs/panel.step are exports rather than sources, kept the
    same way the v2.x gerbers are.
    .gitattributes marks STEP opaque. It is ASCII, so git would otherwise
    eol-normalise it and attempt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
    [panel.step]
2026-08-14 Untrack the 9 MB board STEP export
    It is an output, not a source -- kicad-cli pcb export step regenerates it -- and
    it changes wholesale on every board edit, so tracking it grows history by 9 MB a
    revision for nothing. The panel export is small enough to keep.
    The file stays in the working tree; only the index entry goes.
2026-08-15 Add v3 DigiKey BOM and reorganize references
    Add an upload-ready DigiKey BOM (docs/BOM_v3_DigiKey.csv) and update README/docs to point v2.2 artifacts into a new reference/ directory. Adjust .gitignore for the local Numbers BOM, clarify C9/C10 m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
    [BOM_precision-adder-final-v2.2.csv, BOM_v3_DigiKey.csv, v3-adder.kicad_pcb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]
2026-08-15 gitignore: add editor, OS-junk and KiCad autosave patterns
    Fills the gaps in an otherwise well-covered file: other editors' dirs,
    OS junk, KiCad autosave/fp-cache/report/routing-exchange, and the
    .claude/*.local.json glob alongside the existing explicit entry.
